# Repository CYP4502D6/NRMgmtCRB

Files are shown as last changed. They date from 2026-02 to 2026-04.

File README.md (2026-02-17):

# 5G NGFF Module Carrier Board w/ Out-of-band Management

## Hardware Overview
This project is a hardware carrier board for 5G NGFF (M.2 Key-B) modules, integrating an Allwinner R329-N4 SoC and a Realtek RTL8125BG 2.5GbE network controller.

### Core Components
- **SoC**: Allwinner R329-N4 (Dual-core Cortex-A53, integrated 256MiB DDR3).
- **2.5G NIC**: Realtek RTL8125BG, connected to the 5G module's PCIe interface (requires module to operate in RC mode).
- **Management NIC**: Realtek RTL8211CG, connected to the R329-N4 SoC via RGMII, providing a dedicated 1GbE port.

### Out-of-band Management & Network Architecture
The onboard SoC enables Out-of-band management for the 5G module:
1. **Network Isolation**: The R329-N4 management system features an independent 1GbE port, allowing integration into dedicated management networks such as Homelab IPMI VLANs. This ensures logical and physical isolation from the 5G data traffic segment.
2. **Management Interface**: The R329-N4 communicates with the 5G module through an internal USB for AT command execution, dial-up control, firmware maintenance and accessing modules directly via ADB shell.
3. **External Interfaces**:
    - 1x 2.5GbE RJ45 port (5G module data plane).
    - 1x 1GbE RJ45 port (R329 management plane).
    - 1x USB System Debug UART (for R329).
    - 1x NGFF UART (for Module. Depending on the module definition, it may be either a module system serial port or a COEX Interface serial port).
    - 1x USB Host port (connected to R329).
    - 1x USB Device port (connected to Module, Switch between internal and external USB via DIP switch).

## Manufacturing
- **CAD Tool**: EasyEDA v3.2.80.
- **PCB Stackup**: 6-layer PCB, manufactured using the JLCPCB-3313 stackup process.
- **Impedance Matching**: Configured according to JLC-3313 parameters for USB (90Ω), PCIe differential pairs (100Ω), and RGMII bus signals.

## Gallery
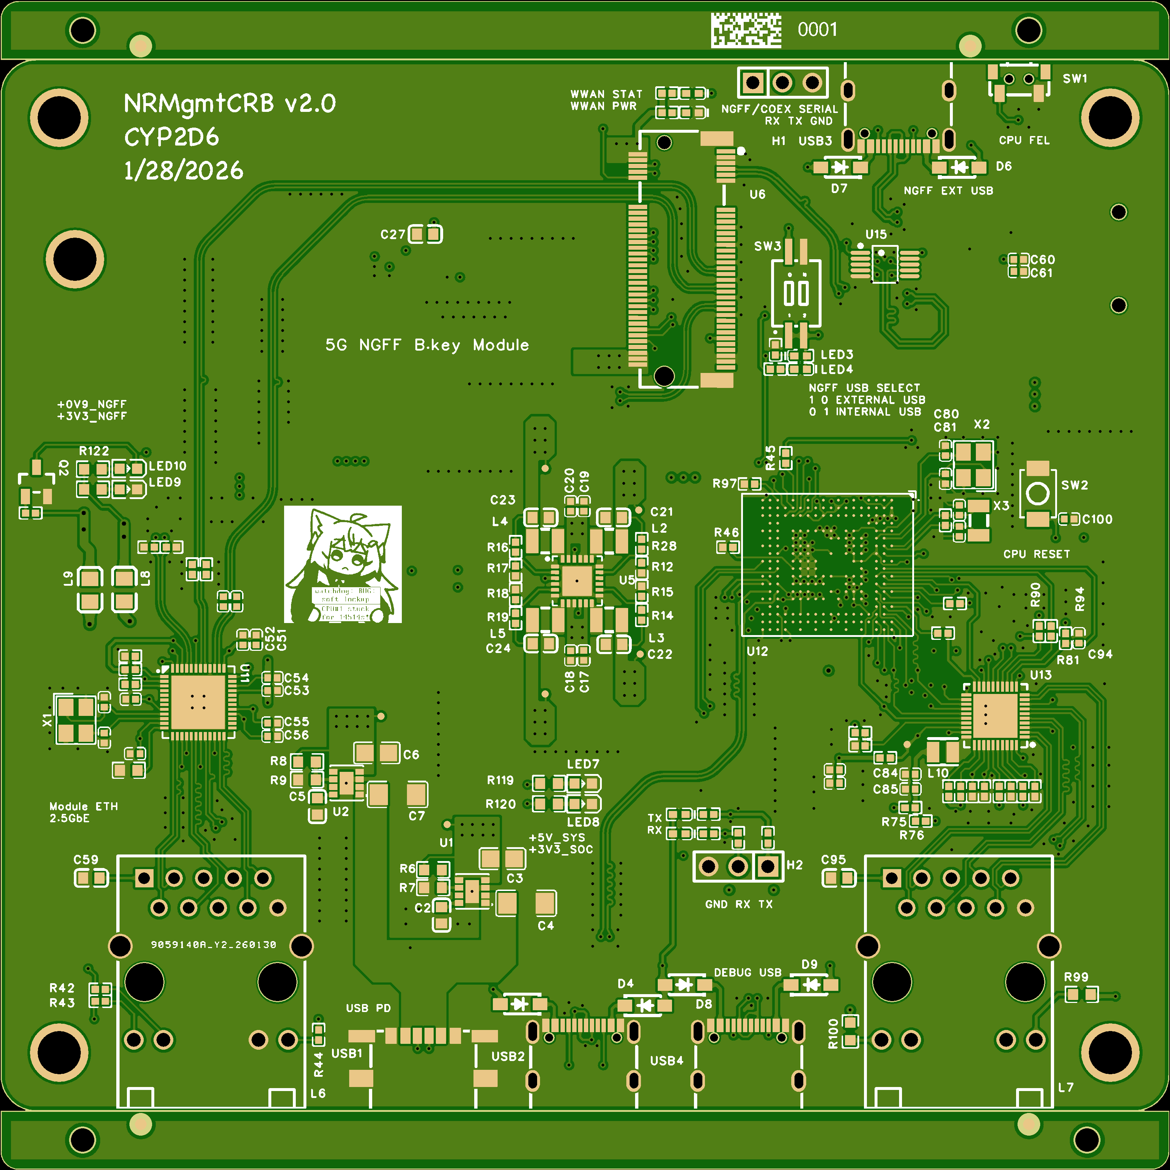
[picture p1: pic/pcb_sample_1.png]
PCB Sample 1

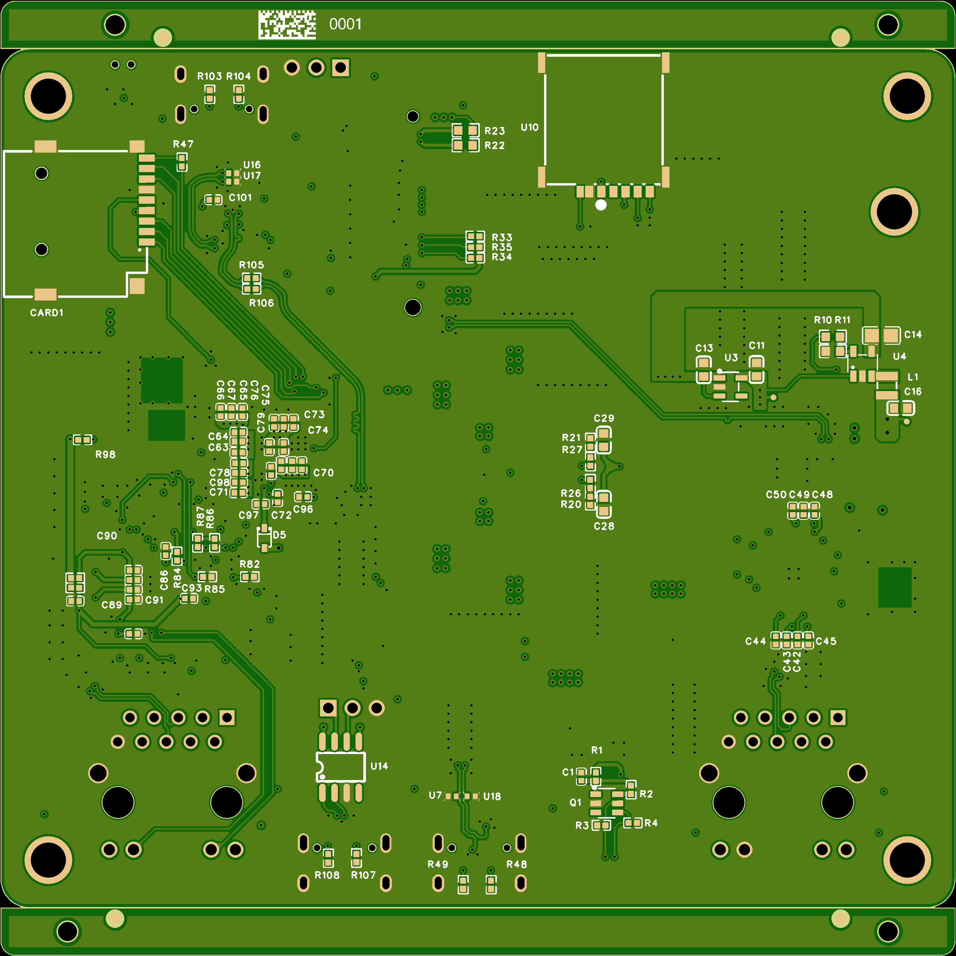
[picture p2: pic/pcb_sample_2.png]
PCB Sample 2

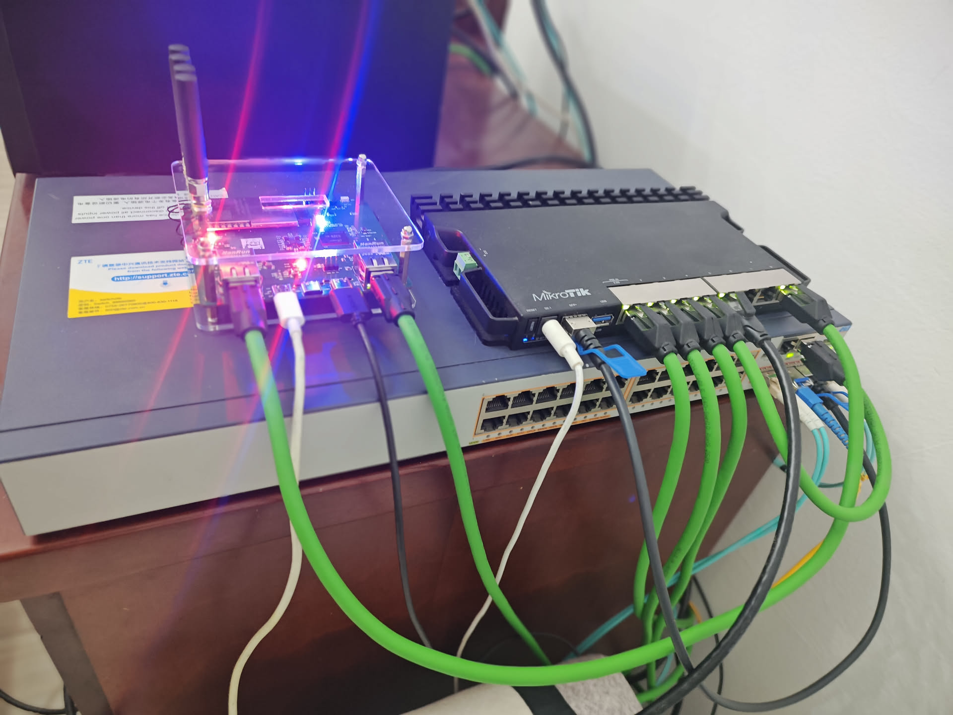
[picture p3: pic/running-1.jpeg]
Running Photo 1

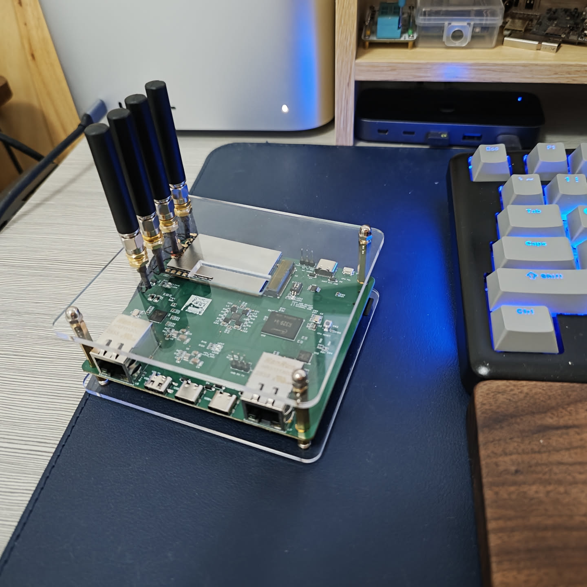
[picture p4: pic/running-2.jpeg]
Running Photo 2


## Bill of Materials
Refer to the file: `./Manufacture/BOM/NRMgmtCRB_v2_PCB1_20260129_230221_BOM.csv`

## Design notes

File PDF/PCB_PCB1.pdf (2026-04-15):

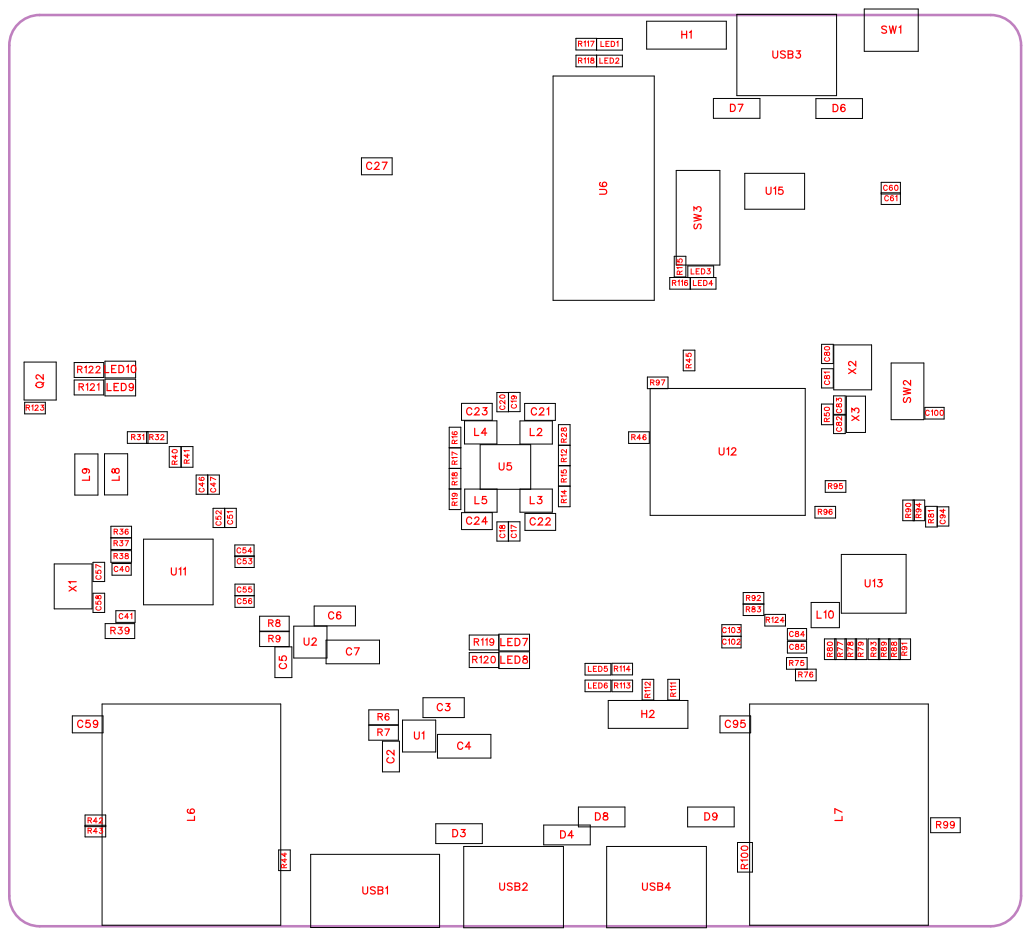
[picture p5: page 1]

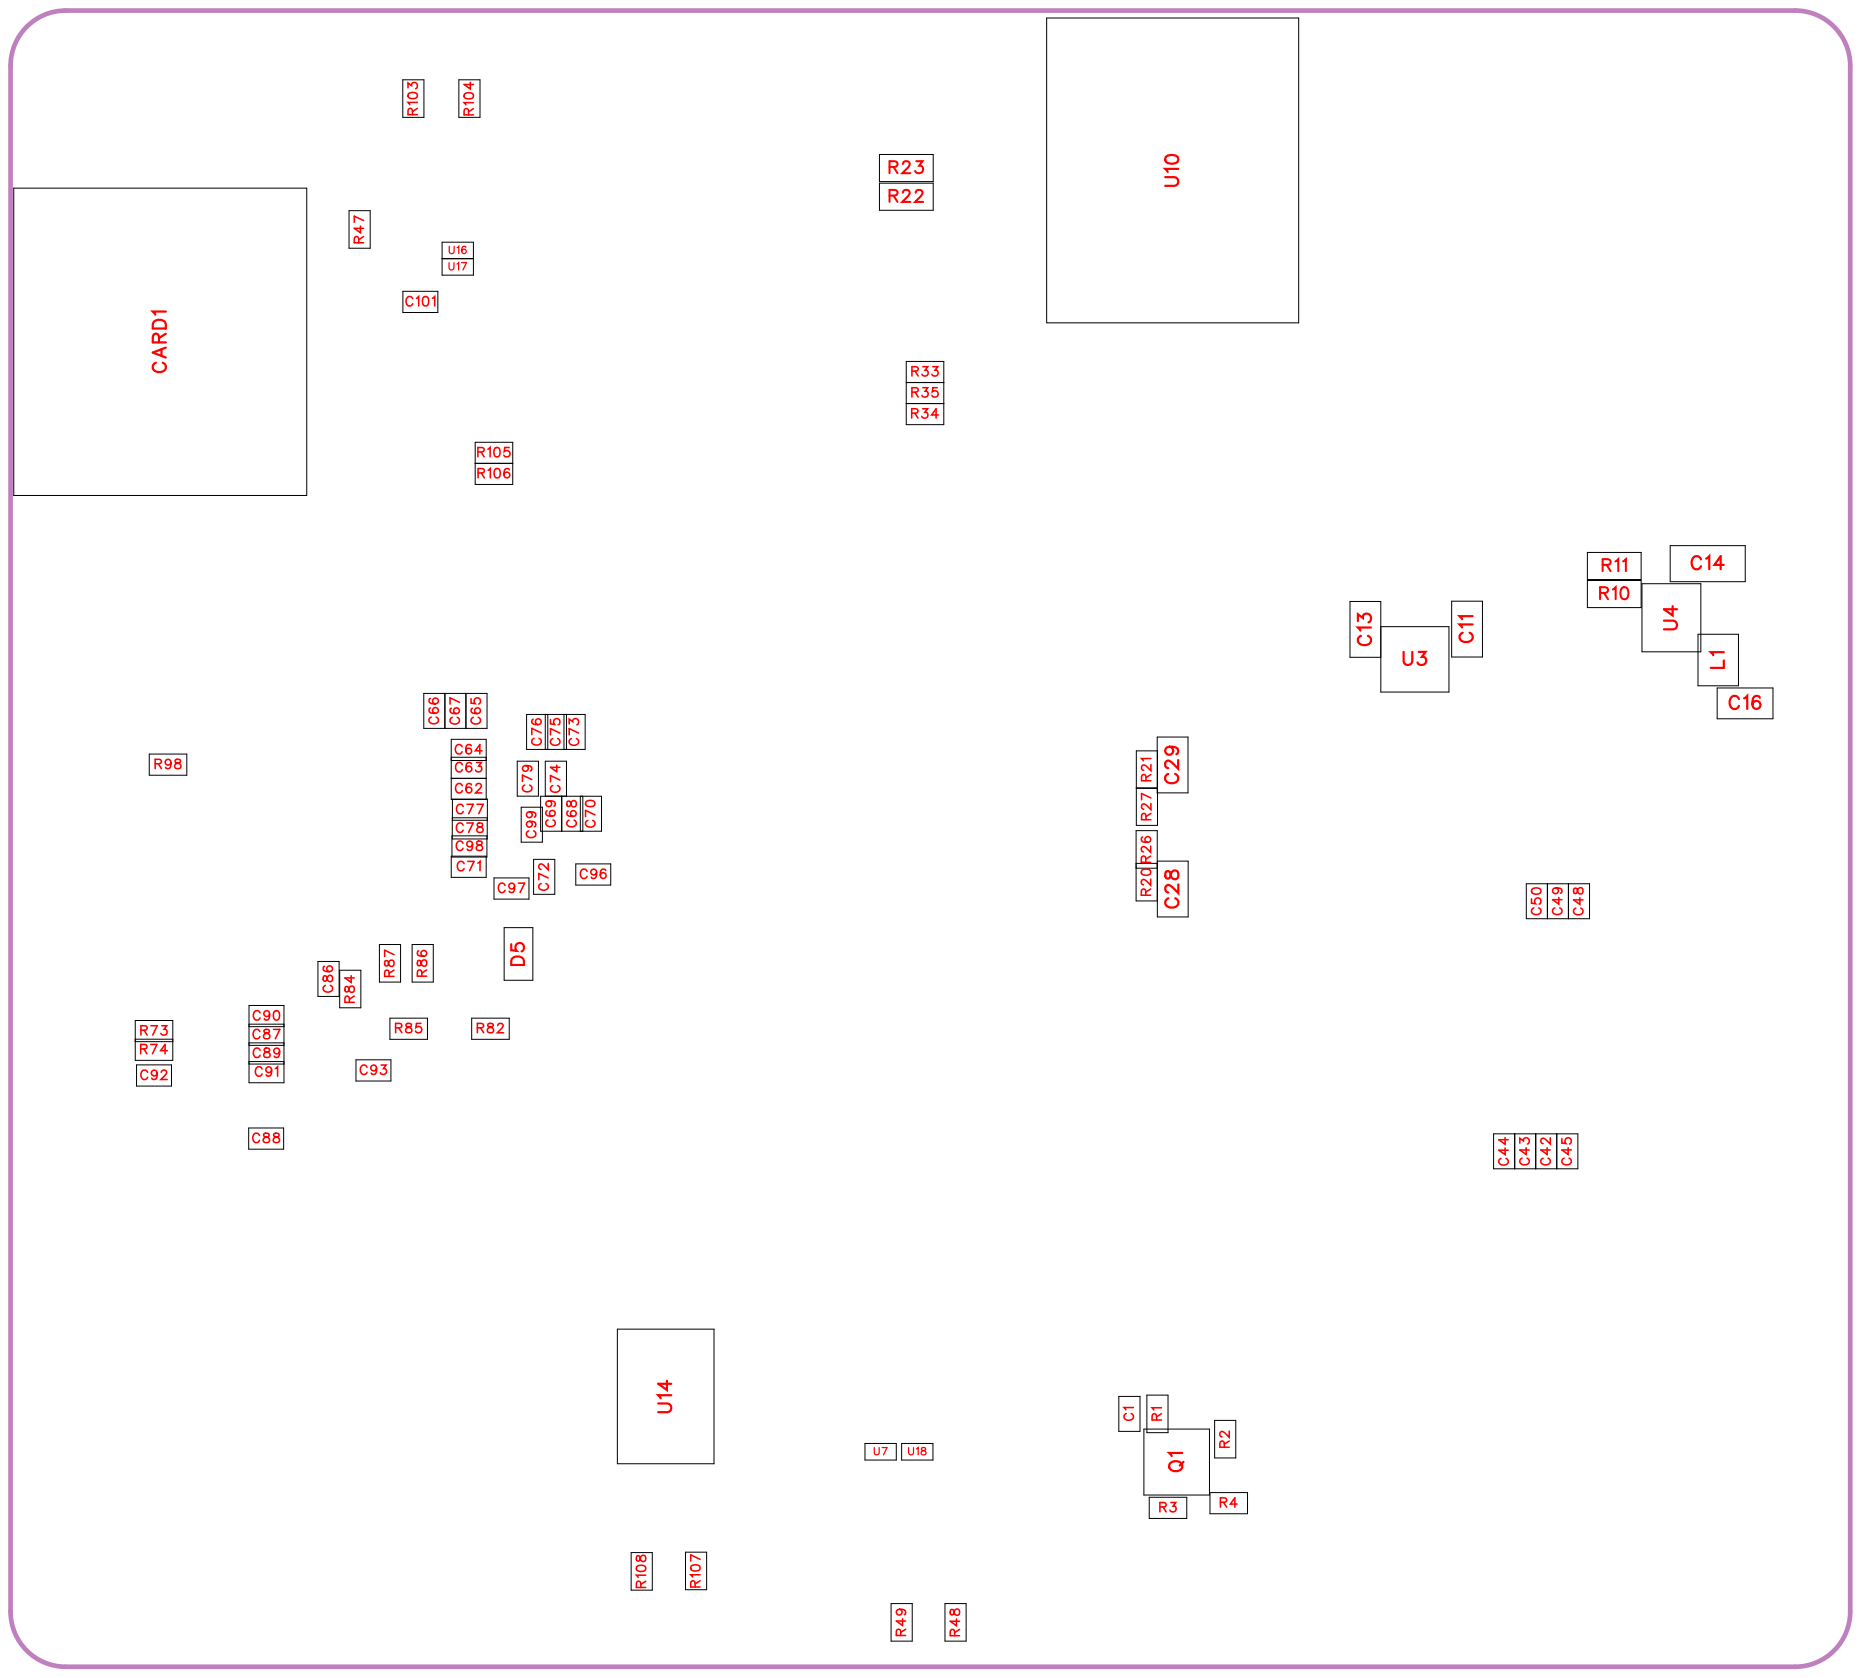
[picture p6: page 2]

No. | Quantity | Comment | Designator | Footprint | Value | Manufacturer Part | Manufacturer | Supplier Part | Supplier
1 | 3 | 1uF | C1,C50,C52 | C0402 | 1uF | CL05A105KA 5NQNC | SAMSUNG( ) 三星 | C52923 | LCSC
2 | 2 | 3.3nF | C2,C5 | C0603 | 3.3nF | CL10B332KB 8NNNC | SAMSUNG( ) 三星 | C1613 | LCSC
3 | 2 | 22uF | C3,C6 | C0805 | 22uF | CL21A226M AQNNNE | SAMSUNG( 三星 ) | C45783 | LCSC
4 | 2 | 10uF | C4,C7 | C1206 | 10uF | CL31A106KB HNNNE | SAMSUNG( 三星 ) | C13585 | LCSC
5 | 2 | 1uF | C11,C13 | C0603 | 1uF | CL10A105KB 8NNNC | SAMSUNG( 三星 ) | C15849 | LCSC
6 | 1 | 4.7uF | C14 | C0805 | 4.7uF | CGA0805X7 R475K350M T | HRE(芯声 ) | C6119943 | LCSC
7 | 1 | 10uF | C16 | C0603 | 10uF | CL10A106KP 8NNNC | SAMSUNG( ) 三星 | C19702 | LCSC
8 | 12 | 10uF | C17,C18,C19,C20,C40,C51 ,C56,C60,C62,C65,C68,C1 01 | C0402 | 10uF | CL05A106M Q5NUNC | SAMSUNG( ) 三星 | C15525 | LCSC
9 | 4 | 22uF | C21,C22,C23,C24 | C0603 | 22uF | CL10A226M Q8NRNC | SAMSUNG( 三星 ) | C59461 | LCSC
10 | 3 | 100nF | C27,C59,C95 | C0603 | 100nF | CC0603KRX 7R9BB104 | YAGEO(国巨 ) | C14663 | LCSC
11 | 2 | 33nF | C28,C29 | C0603 | 33nF | CL10B333KB 8NNNC | SAMSUNG( 三星 ) | C21117 | LCSC
12 | 15 | 2.2uF | C41,C42,C43,C44,C48,C53 ,C54,C63,C64,C66,C67,C9 6,C97,C98,C99 | C0402 | 2.2uF | CL05A225M Q5NSNC | SAMSUNG( ) 三星 | C12530 | LCSC
13 | 27 | 100nF | C45,C46,C47,C49,C55,C61 ,C71,C72,C73,C74,C75,C7 6,C77,C78,C79,C85,C86,C 87,C88,C89,C90,C91,C92, C93,C94,C100,C103 | C0402 | 100nF | CL05B104K O5NNNC | SAMSUNG( ) 三星 | C1525 | LCSC
14 | 2 | 15pF | C57,C58 | C0402 | 15pF | GJM1555C1 H150FB01D | muRata(村田 ) | C441742 | LCSC
15 | 4 | 4.7uF | C69,C70,C84,C102 | C0402 | 4.7uF | CL05A475M P5NRNC | SAMSUNG( ) 三星 | C23733 | LCSC
16 | 4 | 12pF | C80,C81,C82,C83 | C0402 | 12pF | 0402CG120J 500NT | FH(风华 ) | C1547 | LCSC
17 | 1 | TF PUSH | CARD1 | TF-SMD_TF-PUSH | | TF PUSH | SHOU HAN(首韩 ) | C393941 | LCSC
18 | 6 | B5819W SL | D3,D4,D6,D7,D8,D9 | SOD-123_L2 .7-W1.6-LS3. 7-RD-1 | | B5819W SL | CJ(江苏长电 / 长晶 ) | C8598 | LCSC
19 | 1 | 1N4148WS | D5 | SOD-323_L1 .7-W1.3-LS2. 5-FD | | 1N4148WS | R+O(宏嘉诚 ) | C7420319 | LCSC

| 2 | PZ254V-11-0 3P | H1,H2 | HDR-TH_3P-P2.54-V-M_P Z254V-11-03 P | | PZ254V-11-0 3P | XFCN(兴飞 ) | C2937625 | LCSC
21 | 1 | 2.2uH | L1 | IND-SMD_L2 .5-W2.0_MH CHL2520 | 2.2uH | FTC252012S 2R2MBCA | cjiang(长江微 电) | C5832372 | LCSC
22 | 4 | 1.5uH | L2,L3,L4,L5 | IND-SMD_L2 .5-W2.0_YX MBL252010P | 1.5uH | FWP252010 P-1R5ML | cjiang(长江微 电) | C5179452 | LCSC
23 | 2 | HR911130C | L6,L7 | RJ45-TH_HR 911130C | | HR911130C | HANRUN( 汉 仁 ) | C50933 | LCSC
24 | 2 | GZ2012D101 TF | L8,L9 | L0805 | | GZ2012D101 TF | Sunlord(顺络 ) | C1015 | LCSC
25 | 1 | 2.2uH | L10 | IND-SMD_L2 .0-W1.6-B | 2.2uH | FTC201610S 2R2MBCA | cjiang(长江微 电) | C5832344 | LCSC
26 | 6 | SZYY0402B | LED1,LED2,LED3,LED4,LE D5,LED6 | LED0402-RD _BLUE | | SZYY0402B | yongyu(永裕 光电 ) | C434447 | LCSC
27 | 4 | KT-0603R | LED7,LED8,LED9,LED10 | LED0603-RD | | KT-0603R | KENTO | C2286 | LCSC
28 | 1 | CH221K | Q1 | SOT-23-6_L2 .9-W1.6-P0.9 5-LS2.8-BL-2 | | CH221K | WCH(南京沁 恒) | C5125736 | LCSC
29 | 1 | 2N3904S-RT K/PS | Q2 | SOT-23-3_L2 .9-W1.3-P1.9 0-LS2.4-TR | | 2N3904S-RT K/PS | KEC | C18536 | LCSC
30 | 3 | 1k | R1,R37,R47 | R0402 | 1k | 0402WGF10 01TCE | UNI-ROYAL( ) 厚声 | C11702 | LCSC
31 | 2 | 47k | R2,R98 | R0402 | 47k | 0402WGF47 02TCE | UNI-ROYAL( 厚声 ) | C25792 | LCSC
32 | 8 | 5.1k | R3,R4,R48,R49,R103,R104 ,R107,R108 | R0402 | 5.1k | 0402WGF51 01TCE | UNI-ROYAL( 厚声 ) | C25905 | LCSC
33 | 1 | 56k | R6 | R0603 | 56k | 0603WAF56 02T5E | UNI-ROYAL( 厚声 ) | C23206 | LCSC
34 | 1 | 10.5k | R7 | R0603 | 10.5k | 0603WAF10 52T5E | UNI-ROYAL( ) 厚声 | C22855 | LCSC
35 | 1 | 40k | R8 | R0603 | 40k | RT0603BRD 0740KL | YAGEO(国巨 ) | C861392 | LCSC
36 | 1 | 11k | R9 | R0603 | 11k | RC0603FR-0 711KL | YAGEO(国巨 ) | C137801 | LCSC
37 | 1 | 100k | R10 | R0603 | 100k | 0603WAF10 03T5E | UNI-ROYAL( 厚声 ) | C25803 | LCSC
38 | 1 | 49.9k | R11 | R0603 | 49.9k | 0603WAF49 92T5E | UNI-ROYAL( 厚声 ) | C23184 | LCSC
39 | 6 | 10k | R12,R14,R16,R18,R31,R32 | R0402 | 10k | 0402WGF10 02TCE | UNI-ROYAL( ) 厚声 | C25744 | LCSC
40 | 1 | 20k | R15 | R0402 | 20k | 0402WGF20 02TCE | UNI-ROYAL( ) 厚声 | C25765 | LCSC
41 | 1 | 12k | R17 | R0402 | 12k | 0402WGF12 02TCE | UNI-ROYAL( 厚声 ) | C25752 | LCSC

| 3 | 15k | R19,R36,R38 | R0402 | 15k | 0402WGF15 02TCE | UNI-ROYAL( 厚声 ) | C25756 | LCSC
43 | 7 | 100k | R20,R21,R26,R27,R33,R34 ,R35 | R0402 | 100k | 0402WGF10 03TCE | UNI-ROYAL( ) 厚声 | C25741 | LCSC
44 | 2 | 10k | R22,R23 | R0603 | 10k | 0603WAF10 02T5E | UNI-ROYAL( ) 厚声 | C25804 | LCSC
45 | 1 | 45.3k | R28 | R0402 | 45.3k | 0402WGF45 32TCE | UNI-ROYAL( 厚声 ) | C26980 | LCSC
46 | 1 | 2.5k | R39 | R0603 | 2.5k | AR03BTCX2 501 | Viking(光颉 ) | C2984338 | LCSC
47 | 11 | 0 | R40,R41,R42,R73,R74,R75 ,R76,R88,R89,R97,R124 | R0402 | 0 | 0402WGF00 00TCE | UNI-ROYAL( 厚声 ) | C17168 | LCSC
48 | 1 | 330 | R43 | R0402 | 330 | 0402WGF33 00TCE | UNI-ROYAL( ) 厚声 | C25104 | LCSC
49 | 1 | 2k | R44 | R0402 | 2k | 0402WGF20 01TCE | UNI-ROYAL( ) 厚声 | C4109 | LCSC
50 | 6 | 33 | R45,R92,R93,R94,R95,R96 | R0402 | 33 | 0402WGF33 0JTCE | UNI-ROYAL( 厚声 ) | C25105 | LCSC
51 | 1 | 240 | R46 | R0402 | 240 | 0402WGF24 00TCE | UNI-ROYAL( 厚声 ) | C25094 | LCSC
52 | 1 | 1M | R50 | R0402 | 1M | 0402WGF10 04TCE | UNI-ROYAL( 厚声 ) | C26083 | LCSC
53 | 11 | 4.7k | R77,R78,R79,R80,R81,R82 ,R83,R84,R85,R86,R87 | R0402 | 4.7k | 0402WGF47 01TCE | UNI-ROYAL( ) 厚声 | C25900 | LCSC
54 | 1 | 1.5k | R90 | R0402 | 1.5k | 0402WGF15 01TCE | UNI-ROYAL( ) 厚声 | C25867 | LCSC
55 | 1 | 2.49k | R91 | R0402 | 2.49k | 0402WGF24 91TCE | UNI-ROYAL( 厚声 ) | C25884 | LCSC
56 | 2 | 510 | R99,R100 | R0603 | 510 | 0603WAF51 00T5E | UNI-ROYAL( 厚声 ) | C23193 | LCSC
57 | 2 | 22 | R105,R106 | R0402 | 22 | 0402WGF22 0JTCE | UNI-ROYAL( 厚声 ) | C25092 | LCSC
58 | 4 | 100 | R111,R112,R117,R118 | R0402 | 100 | 0402WGF10 00TCE | UNI-ROYAL( ) 厚声 | C25076 | LCSC
59 | 4 | 220 | R113,R114,R115,R116 | R0402 | 220 | 0402WGF22 00TCE | UNI-ROYAL( ) 厚声 | C25091 | LCSC
60 | 1 | 330 | R119 | R0603 | 330 | 0603WAF33 00T5E | UNI-ROYAL( 厚声 ) | C23138 | LCSC
61 | 3 | 150 | R120,R121,R122 | R0603 | 150 | 0603WAF15 00T5E | UNI-ROYAL( 厚声 ) | C22808 | LCSC
62 | 1 | 200 | R123 | R0402 | 200 | 0402WGF20 00TCE | UNI-ROYAL( 厚声 ) | C25087 | LCSC
63 | 1 | TS24CA 250gf 013 | SW1 | SW-SMD_L4 .7-W3.5-P3.3 5-EH | | TS24CA 250gf 013 | SHOU HAN(首韩 ) | C5373430 | LCSC
64 | 1 | TS-1088-AR 02016 | SW2 | SW-SMD_L3 .9-W3.0-P4.4 5 | | TS-1088-AR 02016 | XUNPU(讯普 ) | C720477 | LCSC

| 1 | 1.27-2P TPPT | SW3 | SW-SMD_2P -L5.4-W4.1-P 1.27-LS8.4 | | 1.27-2P TPPT | SHOU HAN(首韩 ) | C7421516 | LCSC
66 | 2 | TPS82130SI LR | U1,U2 | USIP-8_L3.0-W2.8-P0.65-TL-EP | | TPS82130SI LR | TI(德州仪器 ) | C473914 | LCSC
67 | 1 | RT9193-33G B | U3 | SOT-23-5_L3 .0-W1.7-P0.9 5-LS2.8-BL | | RT9193-33G B | RICHTEK( 立 ) 锜 | C15651 | LCSC
68 | 1 | TLV62569DB VR | U4 | SOT-23-5_L3 .0-W1.7-P0.9 5-LS2.8-BR | | TLV62569DB VR | TI(德州仪器 ) | C141836 | LCSC
69 | 1 | EA3059QDR | U5 | VQFN-24_L4 .0-W4.0-P0.5 0-TL-EP2.5 | | EA3059QDR | everanalog( ) 申风 | C111586 | LCSC
70 | 1 | PCIE-67P42 H | U6 | PCIE-SMD_7 5P-P0.50_H YC01B-05N GFF-420 | | PCIE-67P42 H | SOFNG(硕方 ) | C19188865 | LCSC
71 | 4 | RCLAMP052 1T-ES | U7,U16,U17,U18 | DFN1006-2L-BI | | RCLAMP052 1T-ES | ElecSuper( 静 ) 芯微 | C5180263 | LCSC
72 | 1 | XDSM-0240-2183B | U10 | SIM-SMD_X DSM-0240-2 183B | | XDSM-0240-2183B | LX(连欣科技 ) | C7498090 | LCSC
73 | 1 | RTL8125BG-CG | U11 | TQFN-48_L6 .0-W6.0-P0.4 0-BL-EP4.5 | | RTL8125BG-CG | REALTEK( 瑞 昱 ) | C3013605 | LCSC
74 | 1 | R329-N4 | U12 | BGA-228_L1 4.5-W12.0-P 0.65-TL_R32 9-N4 | | R329-N4 | Allwinner( 全 志 ) | C3039724 | LCSC
75 | 1 | RTL8211FI-C G | U13 | QFN-40_L5.0 -W5.0-P0.40-BL-EP3.7 | | RTL8211FI-C G | REALTEK( 瑞 昱 ) | C717681 | LCSC
76 | 1 | CH340N | U14 | SOP-8_L4.9-W3.9-P1.27-LS6.0-BL | | CH340N | WCH(南京沁 恒) | C2977777 | LCSC
77 | 1 | CH442E | U15 | MSOP-10_L3 .0-W3.0-P0.5 0-LS5.0-BL | | CH442E | WCH(南京沁 恒) | C150097 | LCSC
78 | 1 | TYPE-C 6P QT073 | USB1 | USB-C-SMD _TYPE-C-6P -QT073 | | TYPE-C 6P QT073 | SHOU HAN(首韩 ) | C2681548 | LCSC
79 | 3 | TYPE-C 16PIN 2MD(073) | USB2,USB3,USB4 | USB-C-SMD _TYPE-C-6PI N-2MD-073 | | TYPE-C 16PIN 2MD(073) | SHOU HAN(首韩 ) | C2765186 | LCSC
80 | 1 | 25MHz | X1 | CRYSTAL-S MD_4P-L3.2-W2.5-BL | 25MHz | XXCEELNAN F-25MHZ | TAITIEN( 泰 艺电子 ) | C117869 | LCSC
81 | 1 | 24MHz | X2 | CRYSTAL-S MD_4P-L3.2-W2.5-BL | 24MHz | X322524MO B4SI | YXC(扬兴晶 振) | C70590 | LCSC

1 | 32.768kHz | X3 | FC-135R_L3. 2-W1.5
32.768kHz | Q13FC13500

EPSON(爱普 生)

C32346 LCSC

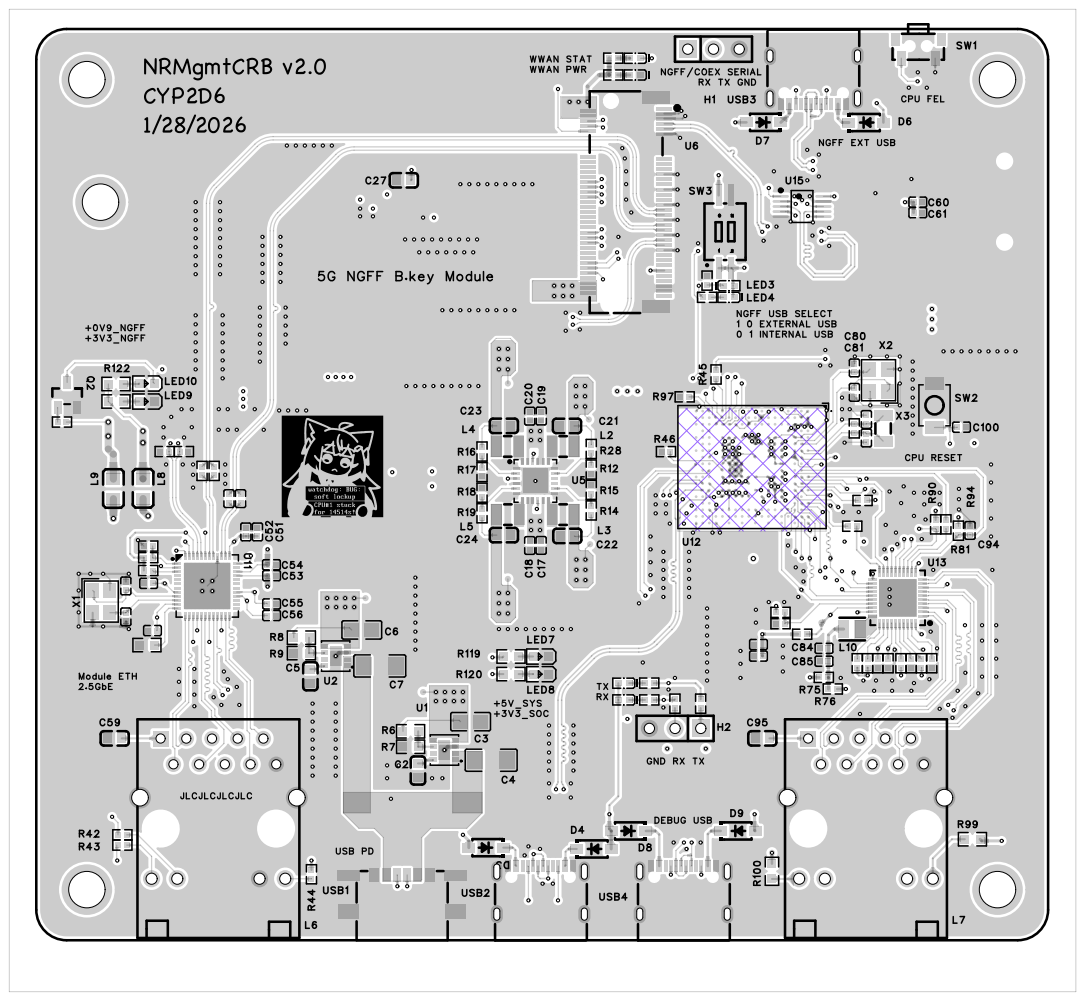
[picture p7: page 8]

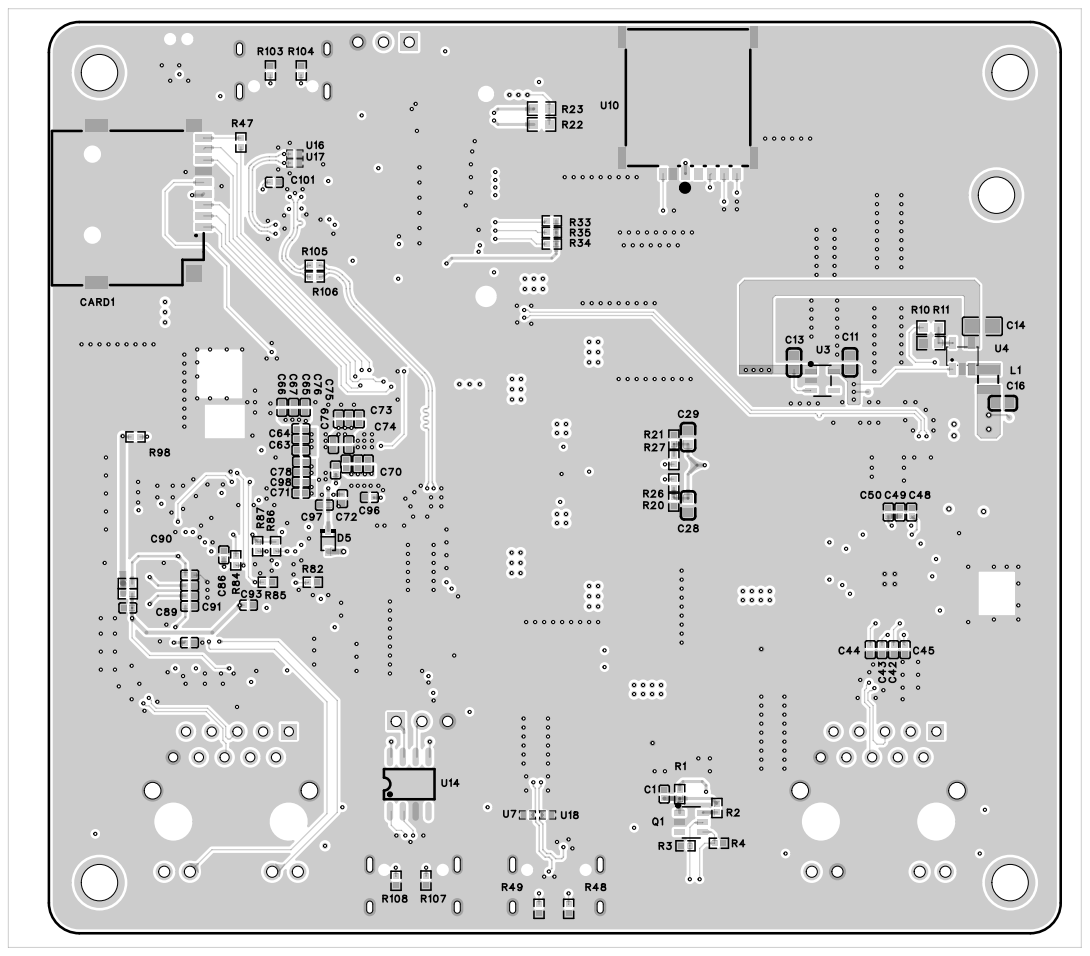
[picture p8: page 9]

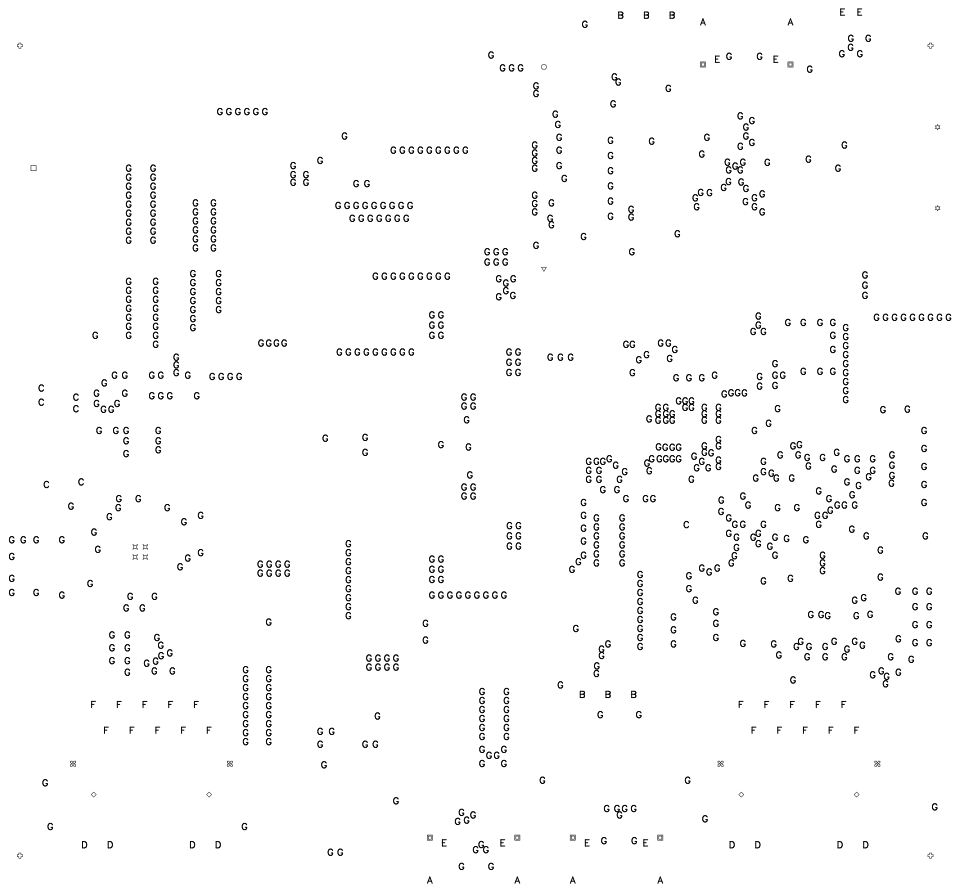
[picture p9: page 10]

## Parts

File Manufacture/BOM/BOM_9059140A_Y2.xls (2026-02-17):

客户BOM清单 |  |  |  |  |  |  |  |  |  | 嘉立创用料信息
No. | Quantity | Comment | Designator | Footprint | Value | ManufacturerPart | Manufacturer | SupplierPart | Supplier | 匹配类型 | 匹配方式 | 匹配来源 | 顶层位号 | 顶层数 | 顶层贴装 | 底层位号 | 底层数 | 底层贴装 | 元件编号 | X-ray检查 | 贴装总数量 | 焊点总数量 | 焊点费小计 | 库类型 | 组装方式 | 元件名称 | 原厂型号 | 封装规格 | 最小起订数量 | 损耗数量 | 元器件来源 | 使用预订数量 | 工厂提供数量 | 工厂元件单价 | 工厂元件小计 | 换料费 | 收费原因
55 | 1 | 2.49kΩ | R91 | R0402 | 2.49kΩ | 0402WGF2491TCE | UNI-ROYAL(厚声) | C25884 | LCSC | 系统识别 | 自动匹配 |  | R91 | 1 | 已贴装 |  | 0 | 已贴装 | C25884 | 不需要 | 4 | 8 | 0.0800 | 扩展库 | 贴装 | 2.49kΩ ±1% 62.5mW 厚膜电阻 | 0402WGF2491TCE | 0402 | 20 | 10 | 商城现货 | 0 | 20 | 0.0038 | 0.0760 | 8.00 | 20个以内不管购买几个，都收费0.0760元
36 | 1 | 11kΩ | R9 | R0603 | 11kΩ | RC0603FR-0711KL | YAGEO(国巨) | C137801 | LCSC | 系统识别 | 自动匹配 |  | R9 | 1 | 已贴装 |  | 0 | 已贴装 | C137801 | 不需要 | 4 | 8 | 0.0800 | 扩展库 | 贴装 | 厚膜电阻 11kΩ ±1% 100mW | RC0603FR-0711KL | 0603 | 20 | 10 | 商城现货 | 0 | 20 | 0.0082 | 0.1640 | 8.00 | 20个以内不管购买几个，都收费0.1640元
24 | 2 | GZ2012D101TF | L8,L9 | L0805 |  | GZ2012D101TF | Sunlord(顺络) | C1015 | LCSC | 系统识别 | 自动匹配 |  | L8, L9 | 2 | 已贴装 |  | 0 | 已贴装 | C1015 | 不需要 | 8 | 16 | 0.1600 | 基础库 | 贴装 | 单路 0805磁珠 阻抗100Ω@100MHz | GZ2012D101TF | 0805 | 20 | 10 | 商城现货 | 0 | 20 | 0.1220 | 2.4400 | 8.00 | 20个以内不管购买几个，都收费2.4400元
38 | 1 | 49.9kΩ | R11 | R0603 | 49.9kΩ | 0603WAF4992T5E | UNI-ROYAL(厚声) | C23184 | LCSC | 系统识别 | 自动匹配 |  |  | 0 | 已贴装 | R11 | 1 | 已贴装 | C23184 | 不需要 | 4 | 8 | 0.0800 | 基础库 | 贴装 | 49.9kΩ ±1% 100mW 厚膜电阻 | 0603WAF4992T5E | 0603 | 20 | 10 | 商城现货 | 0 | 20 | 0.0074 | 0.1480 | 8.00 | 20个以内不管购买几个，都收费0.1480元
73 | 1 | RTL8125BG-CG | U11 | TQFN-48_L6.0-W6.0-P0.40-BL-EP4.5 |  | RTL8125BG-CG | REALTEK(瑞昱) | C3013605 | LCSC | 系统识别 | 自动匹配 |  | U11 | 1 | 已贴装 |  | 0 | 已贴装 | C3013605 | 不需要 | 4 | 196 | 1.9600 | 扩展库 | 贴装 | 集成10/100/1000M/2.5G以太网控制器，适用于PCI Express应用 | RTL8125BG-CG | QFN-48-EP(6x6) | 0 | 0 | 商城现货 | 0 | 4 | 30.4800 | 121.9200 | 8.00
62 | 1 | 200Ω | R123 | R0402 | 200Ω | 0402WGF2000TCE | UNI-ROYAL(厚声) | C25087 | LCSC | 系统识别 | 自动匹配 |  | R123 | 1 | 已贴装 |  | 0 | 已贴装 | C25087 | 不需要 | 4 | 8 | 0.0800 | 基础库 | 贴装 | 200Ω ±1% 62.5mW 厚膜电阻 | 0402WGF2000TCE | 0402 | 20 | 10 | 商城现货 | 0 | 20 | 0.0036 | 0.0720 | 8.00 | 20个以内不管购买几个，都收费0.0720元
46 | 1 | 2.5kΩ | R39 | R0603 | 2.5kΩ | AR03BTCX2501 | Viking(光颉) | C2984338 | LCSC | 系统识别 | 自动匹配 |  | R39 | 1 | 已贴装 |  | 0 | 已贴装 | C2984338 | 不需要 | 4 | 8 | 0.0800 | 扩展库 | 贴装 | 薄膜电阻 2.5kΩ ±0.1% 100mW | AR03BTCX2501 | 0603 | 5 | 8 | 商城现货 | 0 | 12 | 0.2000 | 2.4000 | 8.00 | 5个以内不管购买几个，都收费2.4000元
63 | 1 | TS24CA250gf013 | SW1 | SW-SMD_L4.7-W3.5-P3.35-EH |  | TS24CA250gf013 | SHOUHAN(首韩) | C5373430 | LCSC | 系统识别 | 自动匹配 |  | SW1 | 1 | 已贴装 |  | 0 | 已贴装 | C5373430 | 不需要 | 4 | 16 | 0.1600 | 扩展库 | 贴装 | 2*4*3.5mm半包小贝贝TS-018小侧按键m165蓝牙耳机开关 250gf | TS24CA 250gf 013 | SMD | 10 | 8 | 商城现货 | 0 | 12 | 0.1510 | 1.8120 | 8.00 | 10个以内不管购买几个，都收费1.8120元
2 | 2 | 3.3nF | C2,C5 | C0603 | 3.3nF | CL10B332KB8NNNC | SAMSUNG(三星) | C1613 | LCSC | 系统识别 | 自动匹配 |  | C2, C5 | 2 | 已贴装 |  | 0 | 已贴装 | C1613 | 不需要 | 8 | 16 | 0.1600 | 基础库 | 贴装 | 3.3nF ±10% 50V | CL10B332KB8NNNC | 0603 | 20 | 10 | 商城现货 | 0 | 20 | 0.0339 | 0.6780 | 8.00 | 20个以内不管购买几个，都收费0.6780元
8 | 12 | 10uF | C17,C18,C19,C20,C40,C51,C56,C60,C62,C65,C68,C101 | C0402 | 10uF | CL05A106MQ5NUNC | SAMSUNG(三星) | C15525 | LCSC | 系统识别 | 自动匹配 |  | C17, C18, C19, C20, C40, C51, C56, C60 | 8 | 已贴装 | C62, C65, C68, C101 | 4 | 已贴装 | C15525 | 不需要 | 48 | 96 | 0.9600 | 基础库 | 贴装 | 10uF ±20% 6.3V | CL05A106MQ5NUNC | 0402 | 20 | 20 | 商城现货 | 0 | 68 | 0.0317 | 2.1556 | 8.00
10 | 3 | 100nF | C27,C59,C95 | C0603 | 100nF | CC0603KRX7R9BB104 | YAGEO(国巨) | C14663 | LCSC | 系统识别 | 自动匹配 |  | C27, C59, C95 | 3 | 已贴装 |  | 0 | 已贴装 | C14663 | 不需要 | 12 | 24 | 0.2400 | 基础库 | 贴装 | 100nF ±10% 50V | CC0603KRX7R9BB104 | 0603 | 20 | 10 | 商城现货 | 0 | 22 | 0.0155 | 0.3410 | 8.00 | 20个以内不管购买几个，都收费0.3410元
66 | 2 | TPS82130SILR | U1,U2 | USIP-8_L3.0-W2.8-P0.65-TL-EP |  | TPS82130SILR | TI(德州仪器) | C473914 | LCSC | 系统识别 | 自动匹配 |  | U1, U2 | 2 | 已贴装 |  | 0 | 已贴装 | C473914 | 需要 | 8 | 72 | 0.7200 | 扩展库 | 贴装 | 带集成电感的17V输入、3A降压转换器MicroSiP模块 | TPS82130SILR | USIP-8 | 0 | 0 | 商城现货 | 0 | 8 | 6.2600 | 50.0800 | 8.00
5 | 2 | 1uF | C11,C13 | C0603 | 1uF | CL10A105KB8NNNC | SAMSUNG(三星) | C15849 | LCSC | 系统识别 | 自动匹配 |  |  | 0 | 已贴装 | C11, C13 | 2 | 已贴装 | C15849 | 不需要 | 8 | 16 | 0.1600 | 基础库 | 贴装 | 1uF ±10% 50V | CL10A105KB8NNNC | 0603 | 20 | 10 | 商城现货 | 0 | 20 | 0.0350 | 0.7000 | 8.00 | 20个以内不管购买几个，都收费0.7000元
20 | 2 | PZ254V-11-03P | H1,H2 | HDR-TH_3P-P2.54-V-M_PZ254V-11-03P |  | PZ254V-11-03P | XFCN(兴飞) | C2937625 | LCSC | 系统识别 | 自动匹配 |  | H1, H2 | 2 | 已贴装 |  | 0 | 已贴装 | C2937625 | 不需要 | 8 | 24 | 2.4000 | 扩展库 | 插装 | 1x3P 间距:2.54mm 方针 直插 【插件】 | PZ254V-11-03P | 插件,P=2.54mm | 2 | 2 | 商城现货 | 0 | 10 | 0.0985 | 0.9850 | 0.00
44 | 2 | 10kΩ | R22,R23 | R0603 | 10kΩ | 0603WAF1002T5E | UNI-ROYAL(厚声) | C25804 | LCSC | 系统识别 | 自动匹配 |  |  | 0 | 已贴装 | R22, R23 | 2 | 已贴装 | C25804 | 不需要 | 8 | 16 | 0.1600 | 基础库 | 贴装 | 厚膜电阻 10kΩ ±1% 100mW | 0603WAF1002T5E | 0603 | 20 | 10 | 商城现货 | 0 | 20 | 0.0065 | 0.1300 | 8.00 | 20个以内不管购买几个，都收费0.1300元
34 | 1 | 10.5kΩ | R7 | R0603 | 10.5kΩ | 0603WAF1052T5E | UNI-ROYAL(厚声) | C22855 | LCSC | 系统识别 | 自动匹配 |  | R7 | 1 | 已贴装 |  | 0 | 已贴装 | C22855 | 不需要 | 4 | 8 | 0.0800 | 扩展库 | 贴装 | 10.5kΩ ±1% 100mW 厚膜电阻 | 0603WAF1052T5E | 0603 | 20 | 10 | 商城现货 | 0 | 20 | 0.0081 | 0.1620 | 8.00 | 20个以内不管购买几个，都收费0.1620元
37 | 1 | 100kΩ | R10 | R0603 | 100kΩ | 0603WAF1003T5E | UNI-ROYAL(厚声) | C25803 | LCSC | 系统识别 | 自动匹配 |  |  | 0 | 已贴装 | R10 | 1 | 已贴装 | C25803 | 不需要 | 4 | 8 | 0.0800 | 基础库 | 贴装 | 100kΩ ±1% 100mW 厚膜电阻 | 0603WAF1003T5E | 0603 | 20 | 10 | 商城现货 | 0 | 20 | 0.0066 | 0.1320 | 8.00 | 20个以内不管购买几个，都收费0.1320元
75 | 1 | RTL8211FI-CG | U13 | QFN-40_L5.0-W5.0-P0.40-BL-EP3.7 |  | RTL8211FI-CG | REALTEK(瑞昱) | C717681 | LCSC | 系统识别 | 自动匹配 |  | U13 | 1 | 已贴装 |  | 0 | 已贴装 | C717681 | 不需要 | 4 | 164 | 1.6400 | 扩展库 | 贴装 | 集成10/100/1000M以太网精密收发器 | RTL8211FI-CG | QFN-40-EP(5x5) | 0 | 0 | 商城现货 | 0 | 4 | 15.2900 | 61.1600 | 8.00
40 | 1 | 20kΩ | R15 | R0402 | 20kΩ | 0402WGF2002TCE | UNI-ROYAL(厚声) | C25765 | LCSC | 系统识别 | 自动匹配 |  | R15 | 1 | 已贴装 |  | 0 | 已贴装 | C25765 | 不需要 | 4 | 8 | 0.0800 | 基础库 | 贴装 | 20kΩ ±1% 62.5mW 厚膜电阻 | 0402WGF2002TCE | 0402 | 20 | 10 | 商城现货 | 0 | 20 | 0.0041 | 0.0820 | 8.00 | 20个以内不管购买几个，都收费0.0820元
41 | 1 | 12kΩ | R17 | R0402 | 12kΩ | 0402WGF1202TCE | UNI-ROYAL(厚声) | C25752 | LCSC | 系统识别 | 自动匹配 |  | R17 | 1 | 已贴装 |  | 0 | 已贴装 | C25752 | 不需要 | 4 | 8 | 0.0800 | 基础库 | 贴装 | 12kΩ ±1% 62.5mW 厚膜电阻 | 0402WGF1202TCE | 0402 | 20 | 10 | 商城现货 | 0 | 20 | 0.0037 | 0.0740 | 8.00 | 20个以内不管购买几个，都收费0.0740元
68 | 1 | TLV62569DBVR | U4 | SOT-23-5_L3.0-W1.7-P0.95-LS2.8-BR |  | TLV62569DBVR | TI(德州仪器) | C141836 | LCSC | 系统识别 | 自动匹配 |  |  | 0 | 已贴装 | U4 | 1 | 已贴装 | C141836 | 不需要 | 4 | 20 | 0.2000 | 扩展库 | 贴装 | 降压型 2A 2.5V~5.5V | TLV62569DBVR | SOT-23-5 | 5 | 4 | 商城现货 | 0 | 8 | 0.3590 | 2.8720 | 8.00 | 5个以内不管购买几个，都收费2.8720元
3 | 2 | 22uF | C3,C6 | C0805 | 22uF | CL21A226MAQNNNE | SAMSUNG(三星) | C45783 | LCSC | 系统识别 | 自动匹配 |  | C3, C6 | 2 | 已贴装 |  | 0 | 已贴装 | C45783 | 不需要 | 8 | 16 | 0.1600 | 基础库 | 贴装 | 22uF ±20% 25V | CL21A226MAQNNNE | 0805 | 20 | 8 | 商城现货 | 0 | 20 | 0.1670 | 3.3400 | 8.00 | 20个以内不管购买几个，都收费3.3400元
31 | 2 | 47kΩ | R2,R98 | R0402 | 47kΩ | 0402WGF4702TCE | UNI-ROYAL(厚声) | C25792 | LCSC | 系统识别 | 自动匹配 |  |  | 0 | 已贴装 | R2, R98 | 2 | 已贴装 | C25792 | 不需要 | 8 | 16 | 0.1600 | 基础库 | 贴装 | 47kΩ ±1% 62.5mW 厚膜电阻 | 0402WGF4702TCE | 0402 | 20 | 10 | 商城现货 | 0 | 20 | 0.0039 | 0.0780 | 8.00 | 20个以内不管购买几个，都收费0.0780元
77 | 1 | CH442E | U15 | MSOP-10_L3.0-W3.0-P0.50-LS5.0-BL |  | CH442E | WCH(南京沁恒) | C150097 | LCSC | 系统识别 | 自动匹配 |  | U15 | 1 | 已贴装 |  | 0 | 已贴装 | C150097 | 不需要 | 4 | 40 | 0.4000 | 扩展库 | 贴装 | 5V低阻模拟开关芯片CH442E | CH442E | MSOP-10 | 5 | 0 | 商城现货 | 0 | 5 | 1.9960 | 9.9800 | 8.00 | 5个以内不管购买几个，都收费9.9800元
76 | 1 | CH340N | U14 | SOP-8_L4.9-W3.9-P1.27-LS6.0-BL |  | CH340N | WCH(南京沁恒) | C2977777 | LCSC | 系统识别 | 自动匹配 |  |  | 0 | 已贴装 | U14 | 1 | 已贴装 | C2977777 | 不需要 | 4 | 32 | 0.3200 | 扩展库 | 贴装 | USB2.0芯片CH340 | CH340N | SOP-8 | 0 | 0 | 商城现货 | 0 | 4 | 3.4000 | 13.6000 | 8.00
21 | 1 | 2.2uH | L1 | IND-SMD_L2.5-W2.0_MHCHL2520 | 2.2uH | FTC252012S2R2MBCA | cjiang(长江微电) | C5832372 | LCSC | 系统识别 | 自动匹配 |  |  | 0 | 已贴装 | L1 | 1 | 已贴装 | C5832372 | 不需要 | 4 | 8 | 0.0800 | 扩展库 | 贴装 | 2.2uH ±20% 3.8A | FTC252012S2R2MBCA | 1008 | 5 | 4 | 商城现货 | 0 | 8 | 0.2050 | 1.6400 | 8.00 | 5个以内不管购买几个，都收费1.6400元
58 | 4 | 100Ω | R111,R112,R117,R118 | R0402 | 100Ω | 0402WGF1000TCE | UNI-ROYAL(厚声) | C25076 | LCSC | 系统识别 | 自动匹配 |  | R111, R112, R117, R118 | 4 | 已贴装 |  | 0 | 已贴装 | C25076 | 不需要 | 16 | 32 | 0.3200 | 基础库 | 贴装 | 100Ω ±1% 62.5mW 厚膜电阻 | 0402WGF1000TCE | 0402 | 20 | 10 | 商城现货 | 0 | 26 | 0.0033 | 0.0858 | 8.00 | 20个以内不管购买几个，都收费0.0858元
22 | 4 | 1.5uH | L2,L3,L4,L5 | IND-SMD_L2.5-W2.0_YXMBL252010P | 1.5uH | FWP252010P-1R5ML | cjiang(长江微电) | C5179452 | LCSC | 系统识别 | 自动匹配 |  | L2, L3, L4, L5 | 4 | 已贴装 |  | 0 | 已贴装 | C5179452 | 不需要 | 16 | 32 | 0.3200 | 扩展库 | 贴装 | 1.5uH ±20% 2.6A | FWP252010P-1R5ML | 1008 | 5 | 4 | 商城现货 | 0 | 20 | 0.2660 | 5.3200 | 8.00
52 | 1 | 1MΩ | R50 | R0402 | 1MΩ | 0402WGF1004TCE | UNI-ROYAL(厚声) | C26083 | LCSC | 系统识别 | 自动匹配 |  | R50 | 1 | 已贴装 |  | 0 | 已贴装 | C26083 | 不需要 | 4 | 8 | 0.0800 | 基础库 | 贴装 | 1MΩ ±1% 62.5mW 厚膜电阻 | 0402WGF1004TCE | 0402 | 20 | 10 | 商城现货 | 0 | 20 | 0.0039 | 0.0780 | 8.00 | 20个以内不管购买几个，都收费0.0780元
80 | 1 | 25MHz | X1 | CRYSTAL-SMD_4P-L3.2-W2.5-BL | 25MHz | XXCEELNANF-25MHZ | TAITIEN(泰艺电子) | C117869 | LCSC | 系统识别 | 自动匹配 |  | X1 | 1 | 已贴装 |  | 0 | 已贴装 | C117869 | 不需要 | 4 | 16 | 0.1600 | 扩展库 | 贴装 | 25MHz ±30ppm 10pF | XXCEELNANF-25MHZ | SMD3225-4P | 5 | 2 | 商城现货 | 0 | 6 | 0.9030 | 5.4180 | 8.00 | 5个以内不管购买几个，都收费5.4180元
23 | 2 | HR911130C | L6,L7 | RJ45-TH_HR911130C |  | HR911130C | HANRUN(汉仁) | C50933 | LCSC | 系统识别 | 自动匹配 |  | L6, L7 | 2 | 已贴装 |  | 0 | 已贴装 | C50933 | 不需要 | 8 | 128 | 12.8000 | 扩展库 | 插装 | 弯插 带LED 【以太】 | HR911130C | 弯插 | 0 | 0 | 商城现货 | 0 | 8 | 17.1100 | 136.8800 | 0.00
74 | 1 | R329-N4 | U12 | BGA-228_L14.5-W12.0-P0.65-TL_R329-N4 |  | R329-N4 | Allwinner(全志) | C3039724 | LCSC | 系统识别 | 自动匹配 |  | U12 | 1 | 已贴装 |  | 0 | 已贴装 | C3039724 | 需要 | 4 | 912 | 9.1200 | 扩展库 | 贴装 | 音频应用处理器 | R329-N4 | LFBGA-228 | 0 | 0 | 商城现货 | 0 | 4 | 84.6300 | 338.5200 | 8.00
16 | 4 | 12pF | C80,C81,C82,C83 | C0402 | 12pF | 0402CG120J500NT | FH(风华) | C1547 | LCSC | 系统识别 | 自动匹配 |  | C80, C81, C82, C83 | 4 | 已贴装 |  | 0 | 已贴装 | C1547 | 不需要 | 16 | 32 | 0.3200 | 基础库 | 贴装 | 12pF ±5% 50V | 0402CG120J500NT | 0402 | 20 | 10 | 商城现货 | 0 | 26 | 0.0068 | 0.1768 | 8.00 | 20个以内不管购买几个，都收费0.1768元
12 | 15 | 2.2uF | C41,C42,C43,C44,C48,C53,C54,C63,C64,C66,C67,C96,C97,C98,C99 | C0402 | 2.2uF | CL05A225MQ5NSNC | SAMSUNG(三星) | C12530 | LCSC | 系统识别 | 自动匹配 |  | C41, C53, C54 | 3 | 已贴装 | C42, C43, C44, C48, C63, C64, C66, C67, C96, C97, C98, C99 | 12 | 已贴装 | C12530 | 不需要 | 60 | 120 | 1.2000 | 基础库 | 贴装 | 2.2uF ±20% 6.3V | CL05A225MQ5NSNC | 0402 | 20 | 20 | 商城现货 | 0 | 80 | 0.0161 | 1.2880 | 8.00
64 | 1 | TS-1088-AR02016 | SW2 | SW-SMD_L3.9-W3.0-P4.45 |  | TS-1088-AR02016 | XUNPU(讯普) | C720477 | LCSC | 系统识别 | 自动匹配 |  | SW2 | 1 | 已贴装 |  | 0 | 已贴装 | C720477 | 不需要 | 4 | 8 | 0.0800 | 基础库 | 贴装 | 4*3*2mm 立贴 轻触开关 | TS-1088-AR02016 | SMD,4x3mm | 5 | 4 | 商城现货 | 0 | 8 | 0.2680 | 2.1440 | 8.00 | 5个以内不管购买几个，都收费2.1440元
61 | 3 | 150Ω | R120,R121,R122 | R0603 | 150Ω | 0603WAF1500T5E | UNI-ROYAL(厚声) | C22808 | LCSC | 系统识别 | 自动匹配 |  | R120, R121, R122 | 3 | 已贴装 |  | 0 | 已贴装 | C22808 | 不需要 | 12 | 24 | 0.2400 | 基础库 | 贴装 | 150Ω ±1% 100mW 厚膜电阻 | 0603WAF1500T5E | 0603 | 20 | 10 | 商城现货 | 0 | 22 | 0.0069 | 0.1518 | 8.00 | 20个以内不管购买几个，都收费0.1518元
9 | 4 | 22uF | C21,C22,C23,C24 | C0603 | 22uF | CL10A226MQ8NRNC | SAMSUNG(三星) | C59461 | LCSC | 系统识别 | 自动匹配 |  | C21, C22, C23, C24 | 4 | 已贴装 |  | 0 | 已贴装 | C59461 | 不需要 | 16 | 32 | 0.3200 | 基础库 | 贴装 | 22uF ±20% 6.3V | CL10A226MQ8NRNC | 0603 | 20 | 10 | 商城现货 | 0 | 26 | 0.0592 | 1.5392 | 8.00 | 20个以内不管购买几个，都收费1.5392元
4 | 2 | 10uF | C4,C7 | C1206 | 10uF | CL31A106KBHNNNE | SAMSUNG(三星) | C13585 | LCSC | 系统识别 | 自动匹配 |  | C4, C7 | 2 | 已贴装 |  | 0 | 已贴装 | C13585 | 不需要 | 8 | 16 | 0.1600 | 基础库 | 贴装 | 10uF ±10% 50V | CL31A106KBHNNNE | 1206 | 5 | 4 | 商城现货 | 0 | 12 | 0.3770 | 4.5240 | 8.00
72 | 1 | XDSM-0240-2183B | U10 | SIM-SMD_XDSM-0240-2183B |  | XDSM-0240-2183B | LX(连欣科技) | C7498090 | LCSC | 系统识别 | 自动匹配 |  |  | 0 | 已贴装 | U10 | 1 | 已贴装 | C7498090 | 不需要 | 4 | 44 | 0.4400 | 扩展库 | 贴装 | 自弹式 NanoSIM卡 卡座 | XDSM-0240-2183B | SMD | 0 | 0 | 商城现货 | 0 | 4 | 2.1210 | 8.4840 | 8.00
11 | 2 | 33nF | C28,C29 | C0603 | 33nF | CL10B333KB8NNNC | SAMSUNG(三星) | C21117 | LCSC | 系统识别 | 自动匹配 |  |  | 0 | 已贴装 | C28, C29 | 2 | 已贴装 | C21117 | 不需要 | 8 | 16 | 0.1600 | 基础库 | 贴装 | 33nF ±10% 50V | CL10B333KB8NNNC | 0603 | 20 | 10 | 商城现货 | 0 | 20 | 0.0255 | 0.5100 | 8.00 | 20个以内不管购买几个，都收费0.5100元
6 | 1 | 4.7uF | C14 | C0805 | 4.7uF | CGA0805X7R475K350MT | HRE(芯声) | C6119943 | LCSC | 系统识别 | 自动匹配 |  |  | 0 | 已贴装 | C14 | 1 | 已贴装 | C6119943 | 不需要 | 4 | 8 | 0.0800 | 扩展库 | 贴装 | 4.7uF ±10% 35V | CGA0805X7R475K350MT | 0805 | 20 | 6 | 商城现货 | 0 | 20 | 0.1670 | 3.3400 | 8.00 | 20个以内不管购买几个，都收费3.3400元
42 | 3 | 15kΩ | R19,R36,R38 | R0402 | 15kΩ | 0402WGF1502TCE | UNI-ROYAL(厚声) | C25756 | LCSC | 系统识别 | 自动匹配 |  | R19, R36, R38 | 3 | 已贴装 |  | 0 | 已贴装 | C25756 | 不需要 | 12 | 24 | 0.2400 | 基础库 | 贴装 | 15kΩ ±1% 62.5mW 厚膜电阻 | 0402WGF1502TCE | 0402 | 20 | 10 | 商城现货 | 0 | 22 | 0.0038 | 0.0836 | 8.00 | 20个以内不管购买几个，都收费0.0836元
15 | 4 | 4.7uF | C69,C70,C84,C102 | C0402 | 4.7uF | CL05A475MP5NRNC | SAMSUNG(三星) | C23733 | LCSC | 系统识别 | 自动匹配 |  | C84, C102 | 2 | 已贴装 | C69, C70 | 2 | 已贴装 | C23733 | 不需要 | 16 | 32 | 0.3200 | 基础库 | 贴装 | 4.7uF ±20% 10V | CL05A475MP5NRNC | 0402 | 20 | 20 | 商城现货 | 0 | 40 | 0.0329 | 1.3160 | 8.00 | 20个以内不管购买几个，都收费1.3160元
60 | 1 | 330Ω | R119 | R0603 | 330Ω | 0603WAF3300T5E | UNI-ROYAL(厚声) | C23138 | LCSC | 系统识别 | 自动匹配 |  | R119 | 1 | 已贴装 |  | 0 | 已贴装 | C23138 | 不需要 | 4 | 8 | 0.0800 | 基础库 | 贴装 | 330Ω ±1% 100mW 厚膜电阻 | 0603WAF3300T5E | 0603 | 20 | 10 | 商城现货 | 0 | 20 | 0.0072 | 0.1440 | 8.00 | 20个以内不管购买几个，都收费0.1440元
43 | 7 | 100kΩ | R20,R21,R26,R27,R33,R34,R35 | R0402 | 100kΩ | 0402WGF1003TCE | UNI-ROYAL(厚声) | C25741 | LCSC | 系统识别 | 自动匹配 |  |  | 0 | 已贴装 | R20, R21, R26, R27, R33, R34, R35 | 7 | 已贴装 | C25741 | 不需要 | 28 | 56 | 0.5600 | 基础库 | 贴装 | 100kΩ ±1% 62.5mW 厚膜电阻 | 0402WGF1003TCE | 0402 | 20 | 10 | 商城现货 | 0 | 38 | 0.0042 | 0.1596 | 8.00
25 | 1 | 2.2uH | L10 | IND-SMD_L2.0-W1.6-B | 2.2uH | FTC201610S2R2MBCA | cjiang(长江微电) | C5832344 | LCSC | 系统识别 | 自动匹配 |  | L10 | 1 | 已贴装 |  | 0 | 已贴装 | C5832344 | 不需要 | 4 | 8 | 0.0800 | 扩展库 | 贴装 | 2.2uH ±20% 3A | FTC201610S2R2MBCA | 0806 | 5 | 4 | 商城现货 | 0 | 8 | 0.2720 | 2.1760 | 8.00 | 5个以内不管购买几个，都收费2.1760元
48 | 1 | 330Ω | R43 | R0402 | 330Ω | 0402WGF3300TCE | UNI-ROYAL(厚声) | C25104 | LCSC | 系统识别 | 自动匹配 |  | R43 | 1 | 已贴装 |  | 0 | 已贴装 | C25104 | 不需要 | 4 | 8 | 0.0800 | 基础库 | 贴装 | 330Ω ±1% 62.5mW 厚膜电阻 | 0402WGF3300TCE | 0402 | 20 | 10 | 商城现货 | 0 | 20 | 0.0048 | 0.0960 | 8.00 | 20个以内不管购买几个，都收费0.0960元
49 | 1 | 2kΩ | R44 | R0402 | 2kΩ | 0402WGF2001TCE | UNI-ROYAL(厚声) | C4109 | LCSC | 系统识别 | 自动匹配 |  | R44 | 1 | 已贴装 |  | 0 | 已贴装 | C4109 | 不需要 | 4 | 8 | 0.0800 | 基础库 | 贴装 | 2kΩ ±1% 62.5mW 厚膜电阻 | 0402WGF2001TCE | 0402 | 20 | 10 | 商城现货 | 0 | 20 | 0.0039 | 0.0780 | 8.00 | 20个以内不管购买几个，都收费0.0780元
78 | 1 | TYPE-C6PQT073 | USB1 | USB-C-SMD_TYPE-C-6P-QT073 |  | TYPE-C6PQT073 | SHOUHAN(首韩) | C2681548 | LCSC | 系统识别 | 自动匹配 |  | USB1 | 1 | 已贴装 |  | 0 | 已贴装 | C2681548 | 不需要 | 4 | 40 | 0.4000 | 扩展库 | 贴装 | 6P卧贴母座 | TYPE-C 6P QT073 | SMD | 0 | 0 | 商城现货 | 0 | 4 | 0.4080 | 1.6320 | 8.00
81 | 1 | 24MHz | X2 | CRYSTAL-SMD_4P-L3.2-W2.5-BL | 24MHz | X322524MOB4SI | YXC(扬兴晶振) | C70590 | LCSC | 系统识别 | 自动匹配 |  | X2 | 1 | 已贴装 |  | 0 | 已贴装 | C70590 | 不需要 | 4 | 16 | 0.1600 | 扩展库 | 贴装 | YSX321SL 24MHZ 4P 3225 12PF ±10PPM -40~85℃ (±20PPM) | X322524MOB4SI | SMD3225-4P | 5 | 4 | 商城现货 | 0 | 8 | 0.4340 | 3.4720 | 8.00 | 5个以内不管购买几个，都收费3.4720元
70 | 1 | PCIE-67P42H | U6 | PCIE-SMD_75P-P0.50_HYC01B-05NGFF-420 |  | PCIE-67P42H | SOFNG(硕方) | C19188865 | LCSC | 系统识别 | 自动匹配 |  | U6 | 1 | 已贴装 |  | 0 | 已贴装 | C19188865 | 不需要 | 4 | 276 | 2.7600 | 扩展库 | 贴装 | PCIE-67P42H | PCIE-67P42H | SMD,P=0.5mm,卧贴 | 0 | 0 | 商城现货 | 0 | 4 | 5.1740 | 20.6960 | 8.00
19 | 1 | 1N4148WS | D5 | SOD-323_L1.7-W1.3-LS2.5-FD |  | 1N4148WS | R+O(宏嘉诚) | C7420319 | LCSC | 系统识别 | 自动匹配 |  |  | 0 | 已贴装 | D5 | 1 | 已贴装 | C7420319 | 不需要 | 4 | 8 | 0.0800 | 扩展库 | 贴装 | 1N4148WS | 1N4148WS | SOD-323 | 20 | 10 | 商城现货 | 0 | 20 | 0.0502 | 1.0040 | 8.00 | 20个以内不管购买几个，都收费1.0040元
27 | 4 | KT-0603R | LED7,LED8,LED9,LED10 | LED0603-RD |  | KT-0603R | KENTO | C2286 | LCSC | 系统识别 | 自动匹配 |  | LED7, LED8, LED9, LED10 | 4 | 已贴装 |  | 0 | 已贴装 | C2286 | 不需要 | 16 | 32 | 0.3200 | 基础库 | 贴装 | 0603 红灯 高亮 | KT-0603R | 0603 | 20 | 10 | 商城现货 | 0 | 26 | 0.0372 | 0.9672 | 8.00 | 20个以内不管购买几个，都收费0.9672元
47 | 11 | 0Ω | R40,R41,R42,R73,R74,R75,R76,R88,R89,R97,R124 | R0402 | 0Ω | 0402WGF0000TCE | UNI-ROYAL(厚声) | C17168 | LCSC | 系统识别 | 自动匹配 |  | R40, R41, R42, R75, R76, R88, R89, R97, R124 | 9 | 已贴装 | R73, R74 | 2 | 已贴装 | C17168 | 不需要 | 44 | 88 | 0.8800 | 基础库 | 贴装 | 0Ω ±1% 62.5mW 厚膜电阻 | 0402WGF0000TCE | 0402 | 20 | 20 | 商城现货 | 0 | 66 | 0.0045 | 0.2970 | 8.00
1 | 3 | 1uF | C1,C50,C52 | C0402 | 1uF | CL05A105KA5NQNC | SAMSUNG(三星) | C52923 | LCSC | 系统识别 | 自动匹配 |  | C52 | 1 | 已贴装 | C1, C50 | 2 | 已贴装 | C52923 | 不需要 | 12 | 24 | 0.2400 | 基础库 | 贴装 | 1uF ±10% 25V | CL05A105KA5NQNC | 0402 | 20 | 20 | 商城现货 | 0 | 40 | 0.0204 | 0.8160 | 8.00 | 20个以内不管购买几个，都收费0.8160元
7 | 1 | 10uF | C16 | C0603 | 10uF | CL10A106KP8NNNC | SAMSUNG(三星) | C19702 | LCSC | 系统识别 | 自动匹配 |  |  | 0 | 已贴装 | C16 | 1 | 已贴装 | C19702 | 不需要 | 4 | 8 | 0.0800 | 基础库 | 贴装 | 10uF ±10% 10V | CL10A106KP8NNNC | 0603 | 20 | 10 | 商城现货 | 0 | 20 | 0.0409 | 0.8180 | 8.00 | 20个以内不管购买几个，都收费0.8180元
17 | 1 | TFPUSH | CARD1 | TF-SMD_TF-PUSH |  | TFPUSH | SHOUHAN(首韩) | C393941 | LCSC | 系统识别 | 自动匹配 |  |  | 0 | 已贴装 | CARD1 | 1 | 已贴装 | C393941 | 不需要 | 4 | 52 | 0.5200 | 扩展库 | 贴装 | 9P，自弹式TF卡座 | TF PUSH | SMD | 0 | 0 | 商城现货 | 0 | 4 | 0.3580 | 1.4320 | 8.00
29 | 1 | 2N3904S-RTK/PS | Q2 | SOT-23-3_L2.9-W1.3-P1.90-LS2.4-TR |  | 2N3904S-RTK/PS | KEC | C18536 | LCSC | 系统识别 | 自动匹配 |  | Q2 | 1 | 已贴装 |  | 0 | 已贴装 | C18536 | 不需要 | 4 | 12 | 0.1200 | 扩展库 | 贴装 | 2N3904S-RTK/PS | 2N3904S-RTK/PS | SOT-23 | 10 | 4 | 商城现货 | 0 | 10 | 0.0712 | 0.7120 | 8.00 | 10个以内不管购买几个，都收费0.7120元
18 | 6 | B5819WSL | D3,D4,D6,D7,D8,D9 | SOD-123_L2.7-W1.6-LS3.7-RD-1 |  | B5819WSL | CJ(江苏长电/长晶) | C8598 | LCSC | 系统识别 | 自动匹配 |  | D3, D4, D6, D7, D8, D9 | 6 | 已贴装 |  | 0 | 已贴装 | C8598 | 不需要 | 24 | 48 | 0.4800 | 基础库 | 贴装 | B5819W SL | B5819W SL | SOD-123 | 20 | 8 | 商城现货 | 0 | 32 | 0.1450 | 4.6400 | 8.00
14 | 2 | 15pF | C57,C58 | C0402 | 15pF | GJM1555C1H150FB01D | muRata(村田) | C441742 | LCSC | 系统识别 | 自动匹配 |  | C57, C58 | 2 | 已贴装 |  | 0 | 已贴装 | C441742 | 不需要 | 8 | 16 | 0.1600 | 扩展库 | 贴装 | 15pF ±1% 50V | GJM1555C1H150FB01D | 0402 | 20 | 8 | 商城现货 | 0 | 20 | 0.1370 | 2.7400 | 8.00 | 20个以内不管购买几个，都收费2.7400元
32 | 8 | 5.1kΩ | R3,R4,R48,R49,R103,R104,R107,R108 | R0402 | 5.1kΩ | 0402WGF5101TCE | UNI-ROYAL(厚声) | C25905 | LCSC | 系统识别 | 自动匹配 |  |  | 0 | 已贴装 | R3, R4, R48, R49, R103, R104, R107, R108 | 8 | 已贴装 | C25905 | 不需要 | 32 | 64 | 0.6400 | 基础库 | 贴装 | 5.1kΩ ±1% 62.5mW 厚膜电阻 | 0402WGF5101TCE | 0402 | 20 | 10 | 商城现货 | 0 | 42 | 0.0040 | 0.1680 | 8.00
33 | 1 | 56kΩ | R6 | R0603 | 56kΩ | 0603WAF5602T5E | UNI-ROYAL(厚声) | C23206 | LCSC | 系统识别 | 自动匹配 |  | R6 | 1 | 已贴装 |  | 0 | 已贴装 | C23206 | 不需要 | 4 | 8 | 0.0800 | 基础库 | 贴装 | 56kΩ ±1% 100mW 厚膜电阻 | 0603WAF5602T5E | 0603 | 20 | 10 | 商城现货 | 0 | 20 | 0.0077 | 0.1540 | 8.00 | 20个以内不管购买几个，都收费0.1540元
71 | 4 | RCLAMP0521T-ES | U7,U16,U17,U18 | DFN1006-2L-BI |  | RCLAMP0521T-ES | ElecSuper(静芯微) | C5180263 | LCSC | 系统识别 | 自动匹配 |  |  | 0 | 已贴装 | U7, U16, U17, U18 | 4 | 已贴装 | C5180263 | 不需要 | 16 | 32 | 0.3200 | 扩展库 | 贴装 | 0521/0531，单路双向ESD静电防护器件，20kV，CJ：0.25pF；HDMI/USB/NFC/RF超高速接口通讯防护 | RCLAMP0521T-ES | DFN1006-2L | 20 | 10 | 商城现货 | 0 | 26 | 0.0822 | 2.1372 | 8.00 | 20个以内不管购买几个，都收费2.1372元
79 | 3 | TYPE-C16PIN2MD(073) | USB2,USB3,USB4 | USB-C-SMD_TYPE-C-6PIN-2MD-073 |  | TYPE-C16PIN2MD(073) | SHOUHAN(首韩) | C2765186 | LCSC | 系统识别 | 自动匹配 |  | USB2, USB3, USB4 | 3 | 已贴装 |  | 0 | 已贴装 | C2765186 | 不需要 | 12 | 192 | 1.9200 | 扩展库 | 贴装 | 16P卧贴母座 | TYPE-C 16PIN 2MD(073) | SMD | 2 | 1 | 商城现货 | 0 | 13 | 0.3830 | 4.9790 | 8.00
35 | 1 | 40kΩ | R8 | R0603 | 40kΩ | RT0603BRD0740KL | YAGEO(国巨) | C861392 | LCSC | 系统识别 | 自动匹配 |  | R8 | 1 | 已贴装 |  | 0 | 已贴装 | C861392 | 不需要 | 4 | 8 | 0.0800 | 扩展库 | 贴装 | 薄膜电阻 40kΩ ±0.1% 100mW | RT0603BRD0740KL | 0603 | 20 | 8 | 商城现货 | 0 | 20 | 0.1650 | 3.3000 | 8.00 | 20个以内不管购买几个，都收费3.3000元
53 | 11 | 4.7kΩ | R77,R78,R79,R80,R81,R82,R83,R84,R85,R86,R87 | R0402 | 4.7kΩ | 0402WGF4701TCE | UNI-ROYAL(厚声) | C25900 | LCSC | 系统识别 | 自动匹配 |  | R77, R78, R79, R80, R81, R83 | 6 | 已贴装 | R82, R84, R85, R86, R87 | 5 | 已贴装 | C25900 | 不需要 | 44 | 88 | 0.8800 | 基础库 | 贴装 | 4.7kΩ ±1% 62.5mW 厚膜电阻 | 0402WGF4701TCE | 0402 | 20 | 20 | 商城现货 | 0 | 64 | 0.0039 | 0.2496 | 8.00
54 | 1 | 1.5kΩ | R90 | R0402 | 1.5kΩ | 0402WGF1501TCE | UNI-ROYAL(厚声) | C25867 | LCSC | 系统识别 | 自动匹配 |  | R90 | 1 | 已贴装 |  | 0 | 已贴装 | C25867 | 不需要 | 4 | 8 | 0.0800 | 基础库 | 贴装 | 1.5kΩ ±1% 62.5mW 厚膜电阻 | 0402WGF1501TCE | 0402 | 20 | 10 | 商城现货 | 0 | 20 | 0.0048 | 0.0960 | 8.00 | 20个以内不管购买几个，都收费0.0960元
50 | 6 | 33Ω | R45,R92,R93,R94,R95,R96 | R0402 | 33Ω | 0402WGF330JTCE | UNI-ROYAL(厚声) | C25105 | LCSC | 系统识别 | 自动匹配 |  | R45, R92, R93, R94, R95, R96 | 6 | 已贴装 |  | 0 | 已贴装 | C25105 | 不需要 | 24 | 48 | 0.4800 | 基础库 | 贴装 | 33Ω ±1% 62.5mW 厚膜电阻 | 0402WGF330JTCE | 0402 | 20 | 10 | 商城现货 | 0 | 34 | 0.0041 | 0.1394 | 8.00
39 | 6 | 10kΩ | R12,R14,R16,R18,R31,R32 | R0402 | 10kΩ | 0402WGF1002TCE | UNI-ROYAL(厚声) | C25744 | LCSC | 系统识别 | 自动匹配 |  | R12, R14, R16, R18, R31, R32 | 6 | 已贴装 |  | 0 | 已贴装 | C25744 | 不需要 | 24 | 48 | 0.4800 | 基础库 | 贴装 | 10kΩ ±1% 62.5mW 厚膜电阻 | 0402WGF1002TCE | 0402 | 20 | 10 | 商城现货 | 0 | 34 | 0.0046 | 0.1564 | 8.00
26 | 6 | SZYY0402B | LED1,LED2,LED3,LED4,LED5,LED6 | LED0402-RD_BLUE |  | SZYY0402B | yongyu(永裕光电) | C434447 | LCSC | 系统识别 | 自动匹配 |  | LED1, LED2, LED3, LED4, LED5, LED6 | 6 | 已贴装 |  | 0 | 已贴装 | C434447 | 不需要 | 24 | 48 | 0.4800 | 扩展库 | 贴装 | 蓝灯 | SZYY0402B | 0402 | 20 | 8 | 商城现货 | 0 | 32 | 0.1140 | 3.6480 | 8.00
65 | 1 | 1.27-2PTPPT | SW3 | SW-SMD_2P-L5.4-W4.1-P1.27-LS8.4 |  | 1.27-2PTPPT | SHOUHAN(首韩) | C7421516 | LCSC | 系统识别 | 自动匹配 |  | SW3 | 1 | 已贴装 |  | 0 | 已贴装 | C7421516 | 不需要 | 4 | 16 | 0.1600 | 扩展库 | 贴装 | 1.27-2P贴片平推有LOGO贴膜编带 | 1.27-2P TPPT | SMD,P=1.27mm | 2 | 0 | 商城现货 | 0 | 4 | 3.0210 | 12.0840 | 8.00
45 | 1 | 45.3kΩ | R28 | R0402 | 45.3kΩ | 0402WGF4532TCE | UNI-ROYAL(厚声) | C26980 | LCSC | 系统识别 | 自动匹配 |  | R28 | 1 | 已贴装 |  | 0 | 已贴装 | C26980 | 不需要 | 4 | 8 | 0.0800 | 扩展库 | 贴装 | 45.3kΩ ±1% 62.5mW 厚膜电阻 | 0402WGF4532TCE | 0402 | 20 | 10 | 商城现货 | 0 | 20 | 0.0032 | 0.0640 | 8.00 | 20个以内不管购买几个，都收费0.0640元
30 | 3 | 1kΩ | R1,R37,R47 | R0402 | 1kΩ | 0402WGF1001TCE | UNI-ROYAL(厚声) | C11702 | LCSC | 系统识别 | 自动匹配 |  | R37 | 1 | 已贴装 | R1, R47 | 2 | 已贴装 | C11702 | 不需要 | 12 | 24 | 0.2400 | 基础库 | 贴装 | 1kΩ ±1% 62.5mW 厚膜电阻 | 0402WGF1001TCE | 0402 | 20 | 20 | 商城现货 | 0 | 40 | 0.0035 | 0.1400 | 8.00 | 20个以内不管购买几个，都收费0.1400元
82 | 1 | 32.768kHz | X3 | FC-135R_L3.2-W1.5 | 32.768kHz | Q13FC13500004 | EPSON(爱普生) | C32346 | LCSC | 系统识别 | 自动匹配 |  | X3 | 1 | 已贴装 |  | 0 | 已贴装 | C32346 | 不需要 | 4 | 8 | 0.0800 | 基础库 | 贴装 | 32.768kHz ±20ppm 12.5pF | Q13FC13500004 | SMD3215-2P | 5 | 0 | 商城现货 | 0 | 5 | 1.1130 | 5.5650 | 8.00 | 5个以内不管购买几个，都收费5.5650元
56 | 2 | 510Ω | R99,R100 | R0603 | 510Ω | 0603WAF5100T5E | UNI-ROYAL(厚声) | C23193 | LCSC | 系统识别 | 自动匹配 |  | R99, R100 | 2 | 已贴装 |  | 0 | 已贴装 | C23193 | 不需要 | 8 | 16 | 0.1600 | 基础库 | 贴装 | 510Ω ±1% 100mW 厚膜电阻 | 0603WAF5100T5E | 0603 | 20 | 10 | 商城现货 | 0 | 20 | 0.0071 | 0.1420 | 8.00 | 20个以内不管购买几个，都收费0.1420元
51 | 1 | 240Ω | R46 | R0402 | 240Ω | 0402WGF2400TCE | UNI-ROYAL(厚声) | C25094 | LCSC | 系统识别 | 自动匹配 |  | R46 | 1 | 已贴装 |  | 0 | 已贴装 | C25094 | 不需要 | 4 | 8 | 0.0800 | 扩展库 | 贴装 | 240Ω ±1% 62.5mW 厚膜电阻 | 0402WGF2400TCE | 0402 | 20 | 10 | 商城现货 | 0 | 20 | 0.0036 | 0.0720 | 8.00 | 20个以内不管购买几个，都收费0.0720元
67 | 1 | RT9193-33GB | U3 | SOT-23-5_L3.0-W1.7-P0.95-LS2.8-BL |  | RT9193-33GB | RICHTEK(立锜) | C15651 | LCSC | 系统识别 | 自动匹配 |  |  | 0 | 已贴装 | U3 | 1 | 已贴装 | C15651 | 不需要 | 4 | 20 | 0.2000 | 扩展库 | 贴装 | 3.3V 300mA 5.5V | RT9193-33GB | SOT-23-5 | 5 | 2 | 商城现货 | 0 | 6 | 0.7210 | 4.3260 | 8.00 | 5个以内不管购买几个，都收费4.3260元
59 | 4 | 220Ω | R113,R114,R115,R116 | R0402 | 220Ω | 0402WGF2200TCE | UNI-ROYAL(厚声) | C25091 | LCSC | 系统识别 | 自动匹配 |  | R113, R114, R115, R116 | 4 | 已贴装 |  | 0 | 已贴装 | C25091 | 不需要 | 16 | 32 | 0.3200 | 基础库 | 贴装 | 220Ω ±1% 62.5mW 厚膜电阻 | 0402WGF2200TCE | 0402 | 20 | 10 | 商城现货 | 0 | 26 | 0.0043 | 0.1118 | 8.00 | 20个以内不管购买几个，都收费0.1118元
13 | 27 | 100nF | C45,C46,C47,C49,C55,C61,C71,C72,C73,C74,C75,C76,C77,C78,C79,C85,C86,C87,C88,C89,C90,C91,C92,C93,C94,C100,C103 | C0402 | 100nF | CL05B104KO5NNNC | SAMSUNG(三星) | C1525 | LCSC | 系统识别 | 自动匹配 |  | C46, C47, C55, C61, C85, C94, C100, C103 | 8 | 已贴装 | C45, C49, C71, C72, C73, C74, C75, C76, C77, C78, C79, C86, C87, C88, C89, C90, C91, C92, C93 | 19 | 已贴装 | C1525 | 不需要 | 108 | 216 | 2.1600 | 基础库 | 贴装 | 100nF ±10% 16V | CL05B104KO5NNNC | 0402 | 20 | 20 | 商城现货 | 0 | 128 | 0.0081 | 1.0368 | 8.00
69 | 1 | EA3059QDR | U5 | VQFN-24_L4.0-W4.0-P0.50-TL-EP2.5 |  | EA3059QDR | everanalog(申风) | C111586 | LCSC | 系统识别 | 自动匹配 |  | U5 | 1 | 已贴装 |  | 0 | 已贴装 | C111586 | 不需要 | 4 | 100 | 1.0000 | 扩展库 | 贴装 | 四路电源管理集成电路 | EA3059QDR | QFN-24-EP(4x4) | 0 | 0 | 商城现货 | 0 | 4 | 3.2900 | 13.1600 | 8.00
57 | 2 | 22Ω | R105,R106 | R0402 | 22Ω | 0402WGF220JTCE | UNI-ROYAL(厚声) | C25092 | LCSC | 系统识别 | 自动匹配 |  |  | 0 | 已贴装 | R105, R106 | 2 | 已贴装 | C25092 | 不需要 | 8 | 16 | 0.1600 | 基础库 | 贴装 | 22Ω ±1% 62.5mW 厚膜电阻 | 0402WGF220JTCE | 0402 | 20 | 10 | 商城现货 | 0 | 20 | 0.0044 | 0.0880 | 8.00 | 20个以内不管购买几个，都收费0.0880元
28 | 1 | CH221K | Q1 | SOT-23-6_L2.9-W1.6-P0.95-LS2.8-BL-2 |  | CH221K | WCH(南京沁恒) | C5125736 | LCSC | 系统识别 | 自动匹配 |  |  | 0 | 已贴装 | Q1 | 1 | 已贴装 | C5125736 | 不需要 | 4 | 24 | 0.2400 | 扩展库 | 贴装 | CH221K | CH221K | SOT-23-6 | 5 | 0 | 邮寄 | 0 | 0 | 0.0000 | 0 | 8.00 | 5个以内不管贴几个，都需邮寄5个

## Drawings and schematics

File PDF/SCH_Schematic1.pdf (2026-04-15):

# PD 12V to 5V

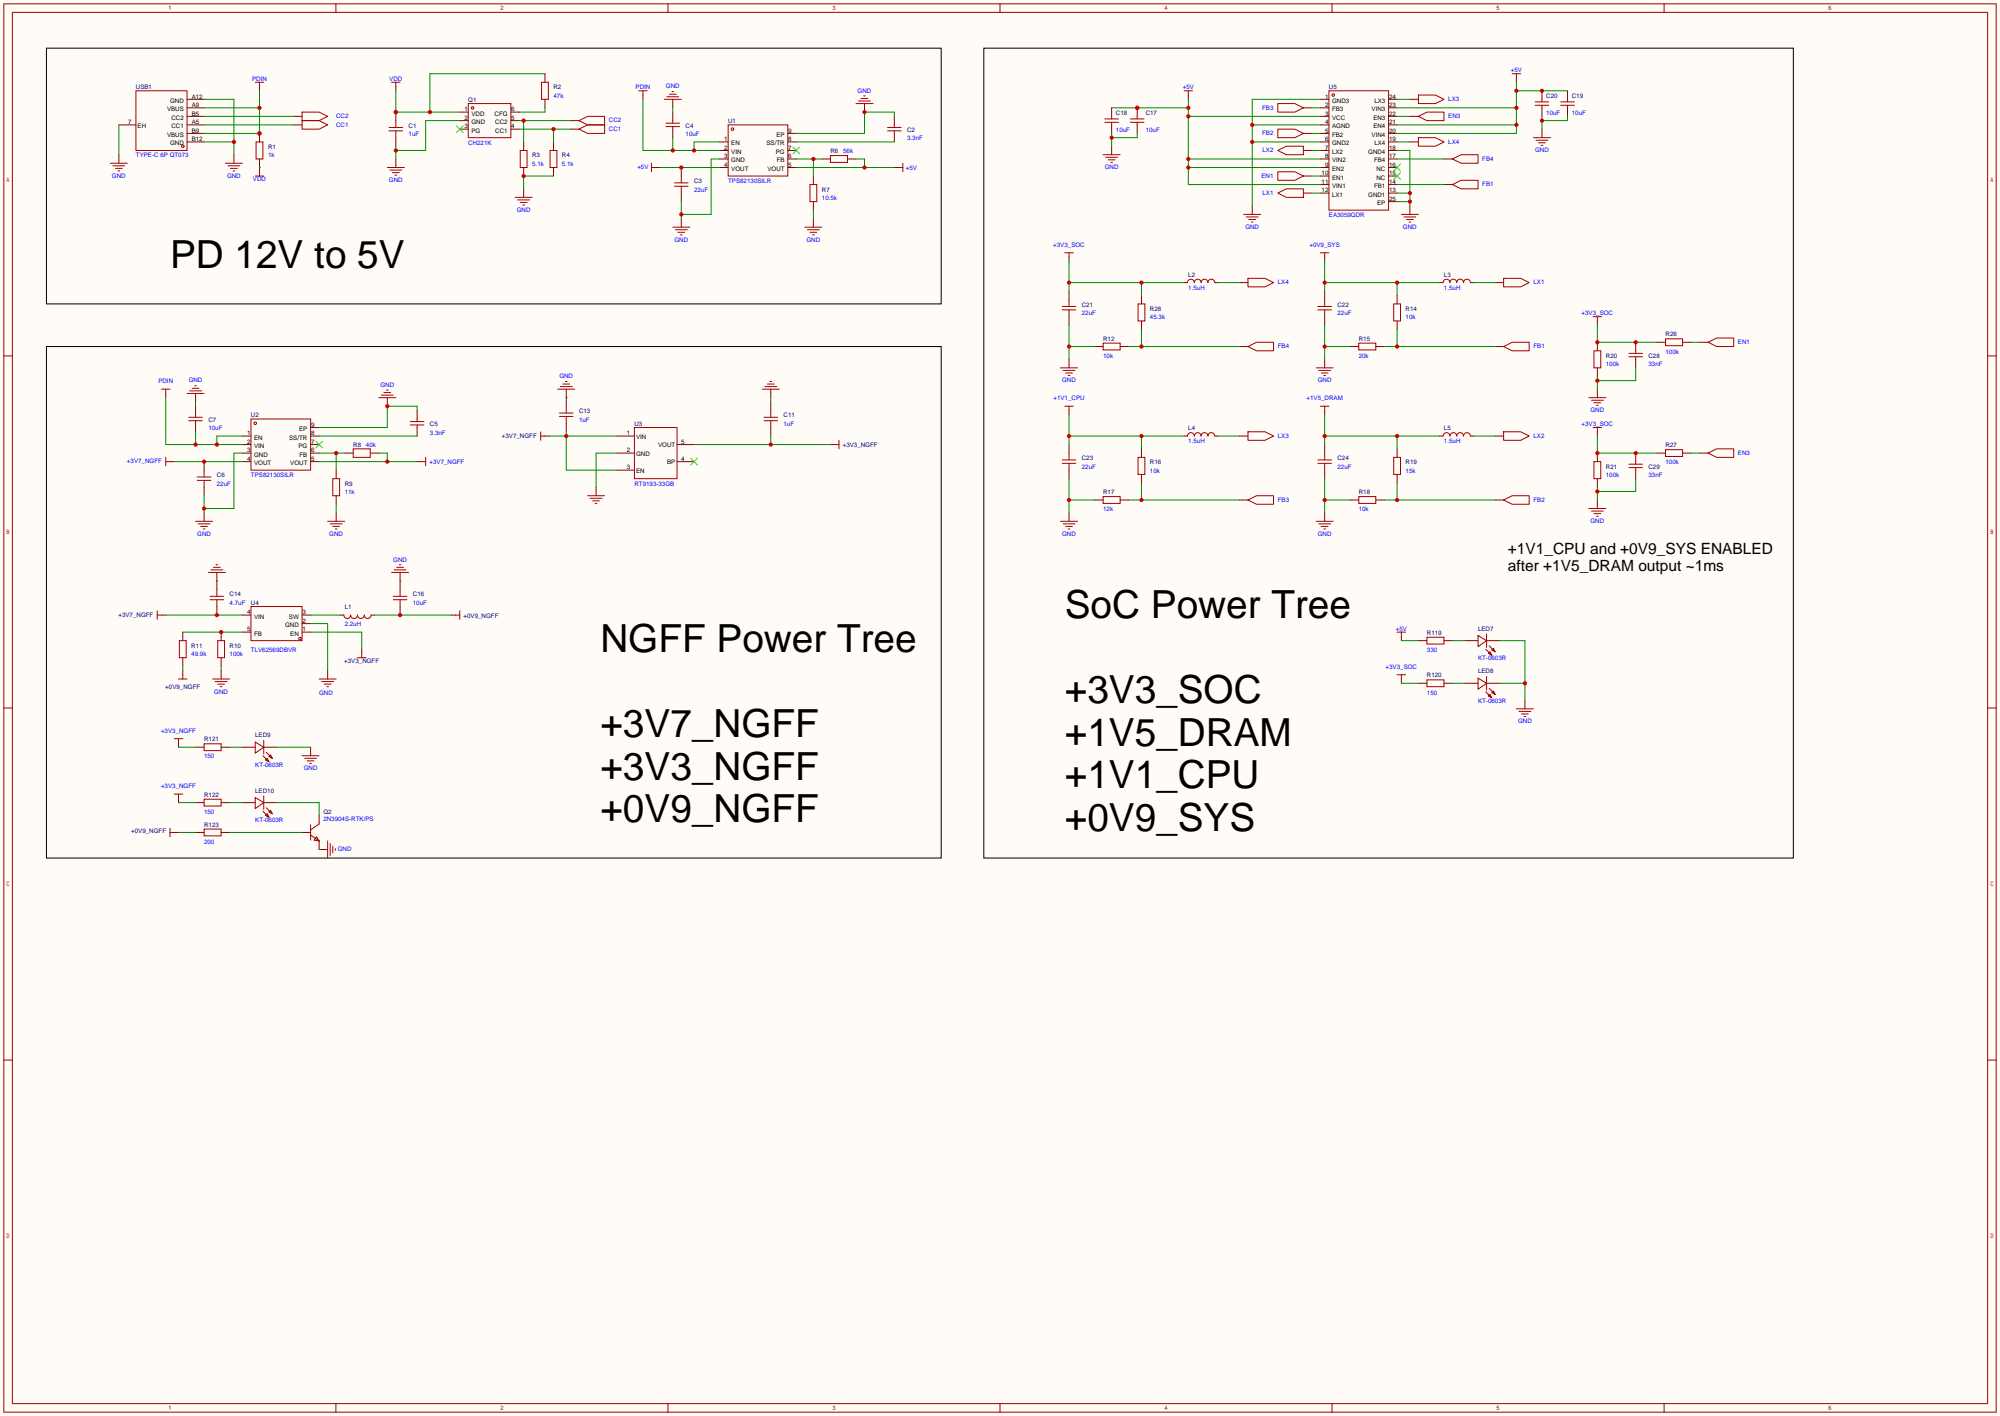
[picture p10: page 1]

57 57 59 59 61 61 63 63 65 65

# 5GLED GND

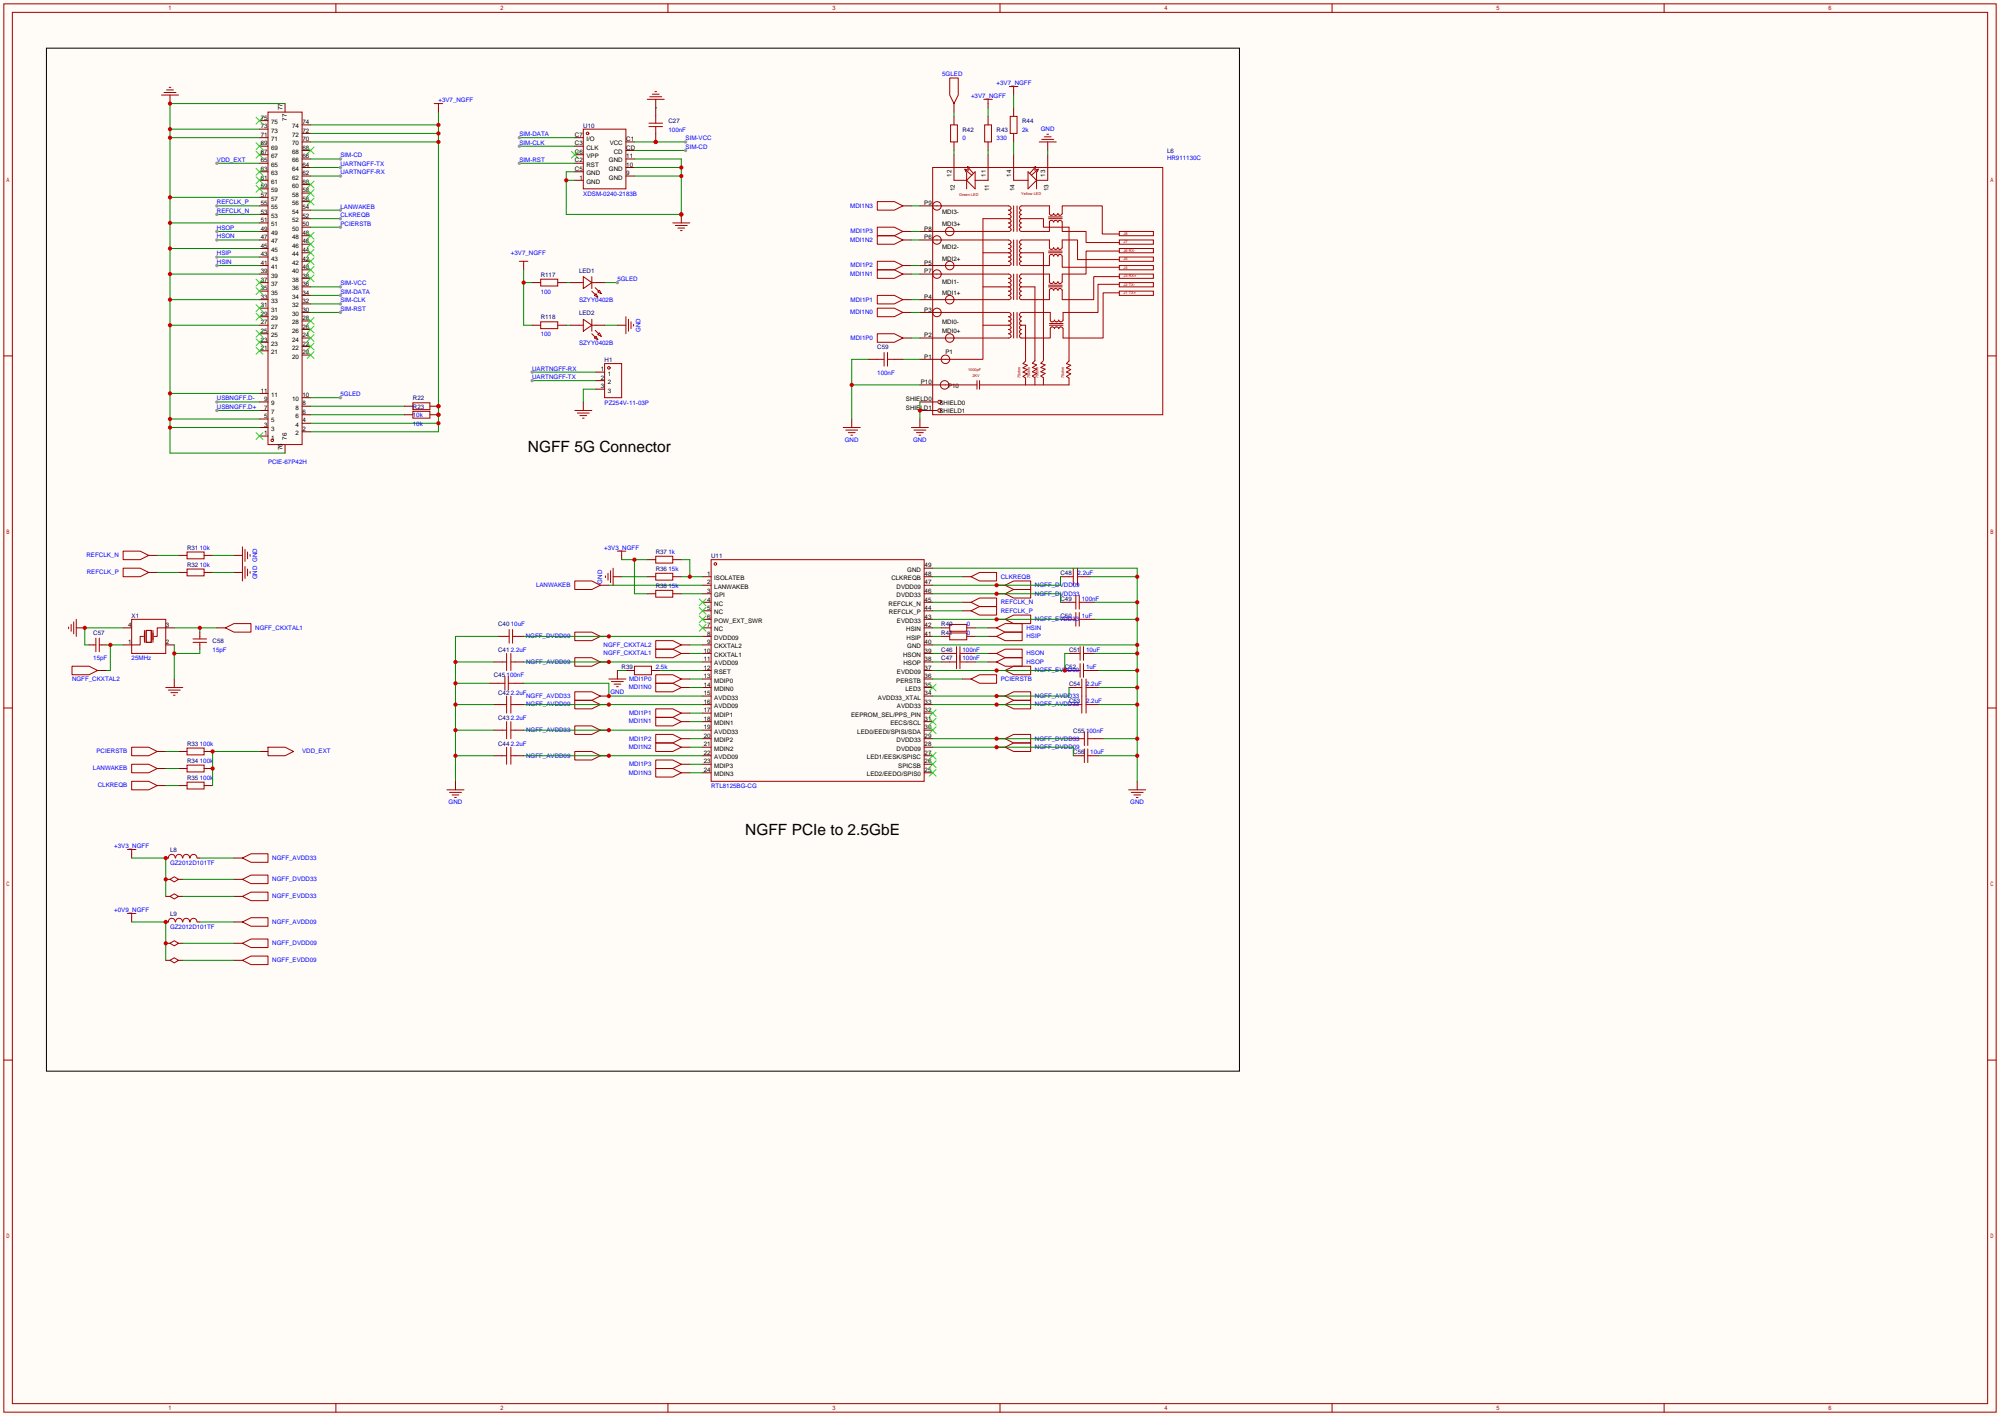
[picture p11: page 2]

GND 10 GND 11 CD CD VCC C1

GND K3 VCC-PG K5 VCC-DRAM K11 VCC-DRAM K12 GND K14 LRADC K16 GPADC3 K17 PG7 L2 PG6 L3 VCC-PF L5 GND L9 GND L10 GND L11 VCC-DRAM L12 GND L14 GPADC2 L16 GPADC1 L17 GPADC0 L18 PG8 M1 PG9 M2 GND M3 GND M5 GND M7 GND M8 GND M9 GND M10 GND M11 VCC-DRAM M12 GND M13 GND M14 MICIN1P M16 MICIN1N M17 PF0 N2 PF1 N3 GND N5 GND N6 GND N7 GND N8 GND N9 GND N10 GND N11 VCC-DRAM N12 GND N13 GND N14 GND N16 MICIN2P N17 MICIN2N N18 PF2 P1 PF3 P2 PF4 P3 GND P5 GND P6 GND P7 GND P8 GND P9 DZQ P10 VCC-DRAM P11 VCC-DRAM P12 GND P13 GND P14 MICIN3P P16 MICIN3N P17 PF5 R2 PF6 R3 AVCC R16 MBIAS R17 AGND R18 PC7 T1 PC6 T2 PC3 T3 PH0 T4 PH2 T5 PH5 T6 PH7 T7 FEL T8 PB7 T9 PB4 T10 PB2 T11 GND T12 USB0-DP T13 GND T14 SPKLP T15 GND T16 VRP T17 VRRA2 T18 PC5 U1 PC4 U2 PC1 U3 PH1 U4 PH3 U5 PH6 U6 PH8 U7 PB8 U8 PB6 U9 PB3 U10 PB1 U11 USB1-DP U12 USB0-DM U13 SPKRP U14 SPKLN U15 MICIN5P U16 MICIN4P U17 VRA1 U18 GND V1 PC2 V2 PC0 V3 PH4 V5 PH9 V7 PB5 V9 PB0 V11 USB1-DM V12 SPKRN V14 MICIN5N V16 MICIN4N V17 GND V18

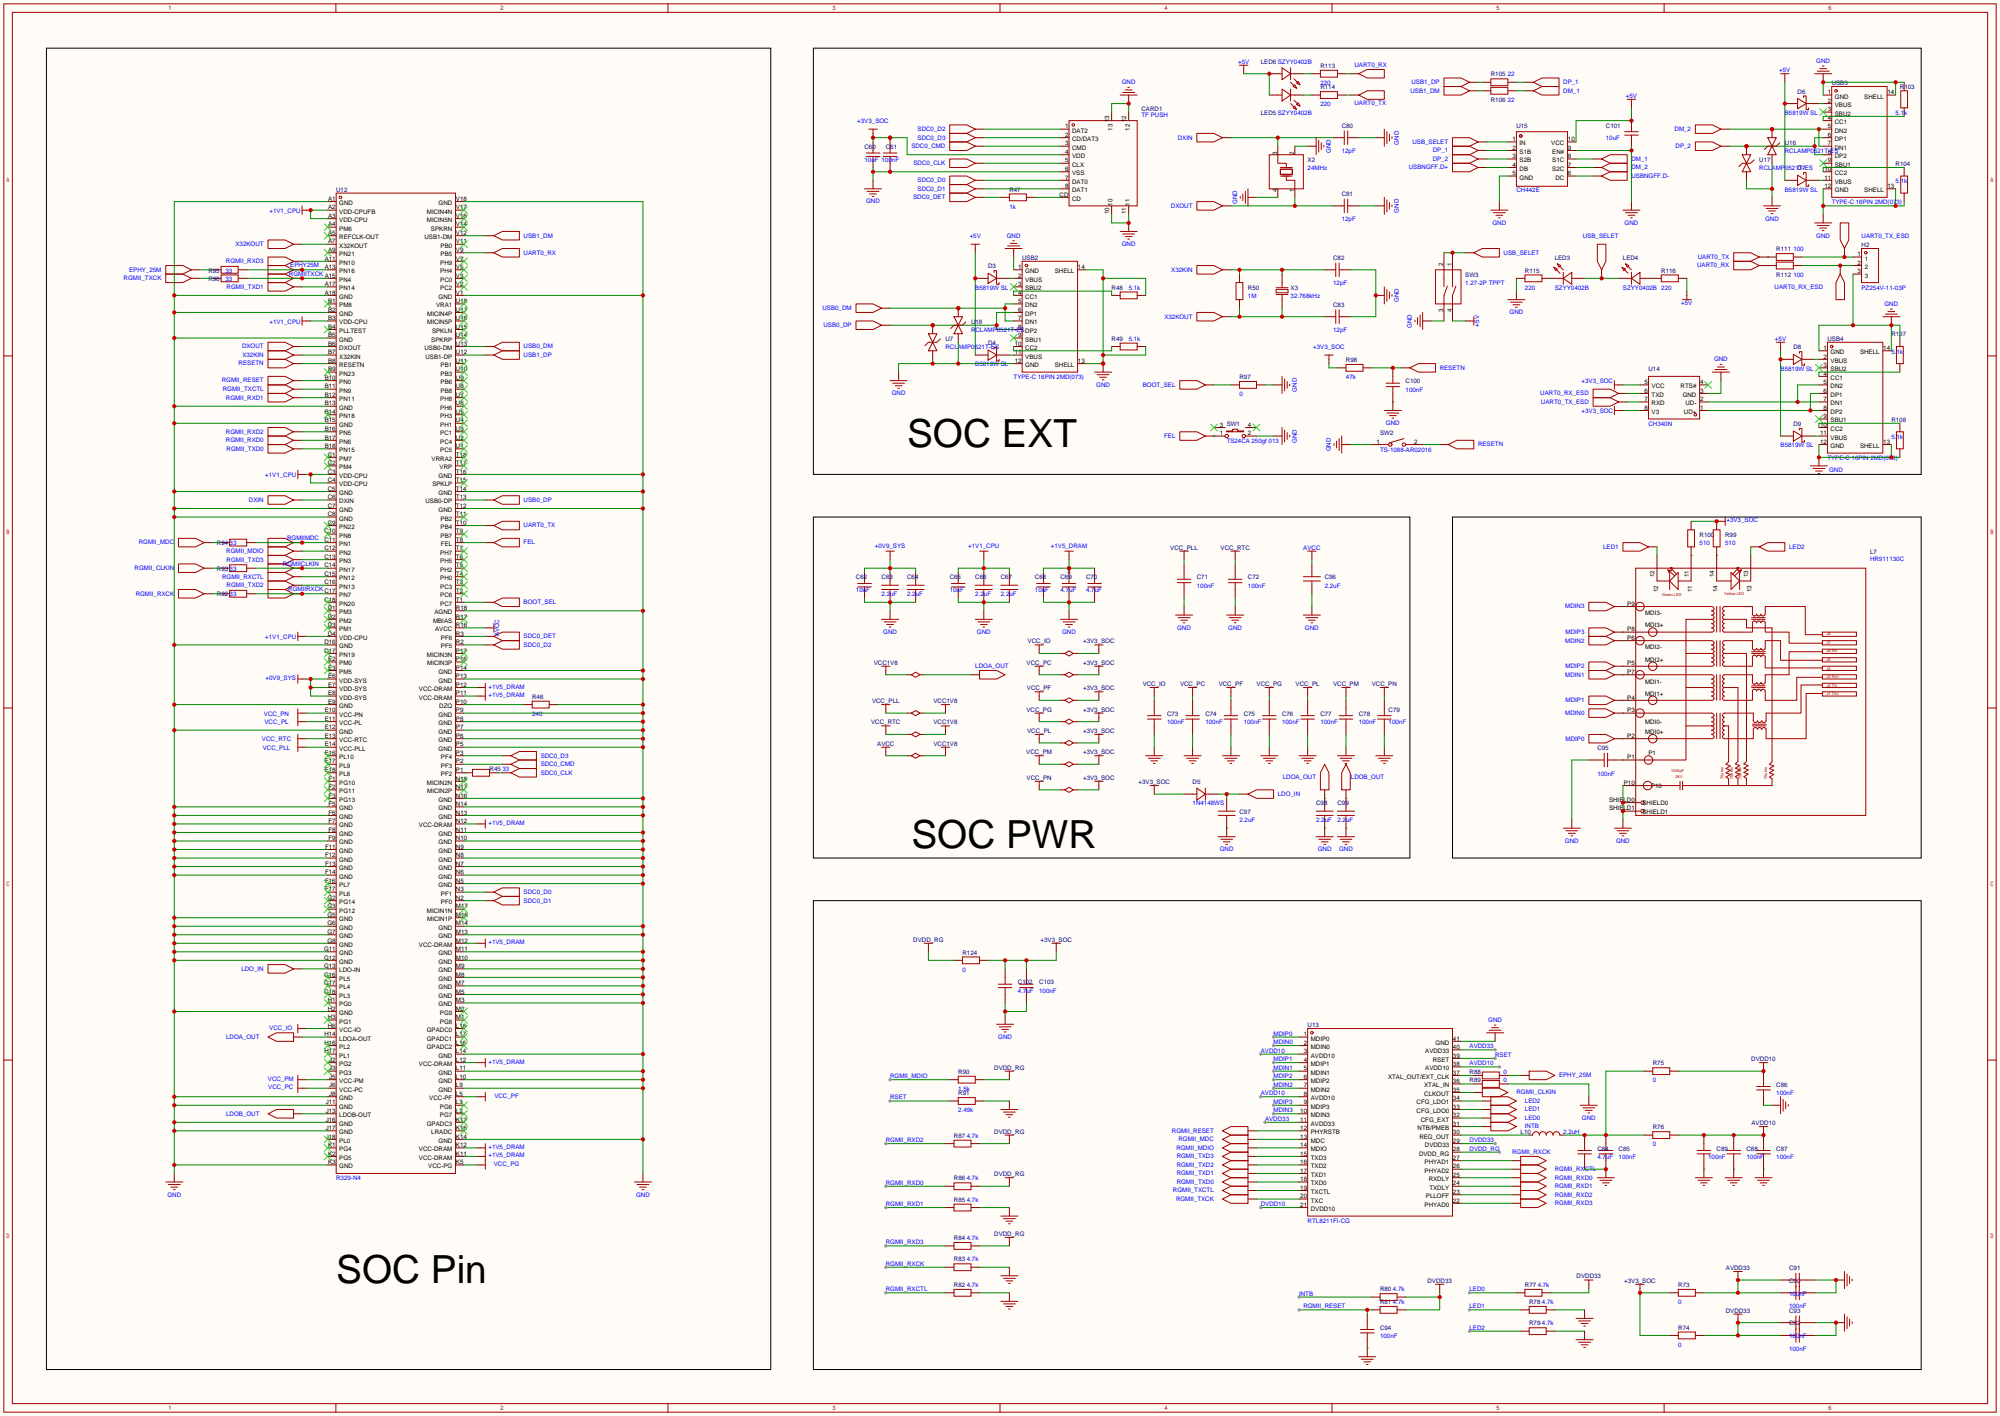
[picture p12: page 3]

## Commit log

2026-02-17 add source files and README.md
    [BOM_9059140A_Y2.xls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]
2026-04-15 add layout and schematic pdf file
